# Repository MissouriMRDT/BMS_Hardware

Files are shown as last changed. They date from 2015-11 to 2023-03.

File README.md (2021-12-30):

Battery Management System- this year it DOES THINGS (for real though!).

New for 2022: <br/>
-Designed to monitor an 8s8p LiPo battery pack at a max 33.6V @ 160A peak. <br/>
-The Cell Monitoring circuit uses the AS358MTR-E1 Op-Amp as it could be powered off of pack voltage. <br/>
-Teensy 4.1 used as microcontroller for the board.

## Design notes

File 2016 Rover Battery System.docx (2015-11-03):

2016 Rover Battery System

Mars Rover Design Team

Student Design and Experiential Learning Center

Missouri University of Science and Technology

Josh Jetter

July 10, 2015

Revision History

Table of Contents

List of Figures

List of Tables

Introduction

Battery Pack

Battery Cells

Cell Modules

Battery Management System

Requirements

System Architecture

Monitoring Analog Front-End

Microcontroller

Pack Load Switch

Cooling Fans

Indicators

Serial Data Interface

System Power Supply

Software

Battery Charger

Charging Requirements

Buck-Converter Design

High-Level Converter Design

Inductor Selection

MOSFET Switch Selection

MOSFET Driver Selection

Diode Selection

Filtering Capacitor Selection

Total Losses

Monitoring and Control Hardware

Schematic

Controls Modeling

Software

PCB Layout

Future Work

Acknowledgments

References

Appendices

Appendix A: Inductor Calculations Octave Source Code

List of Figures

List of Tables

Introduction

The battery system for the 2016 rover encompasses everything necessary for the battery pack’s operation, which includes the battery management system, the battery charger, and the battery cells themselves.

Battery Pack

Battery Management System

A core component of the rover’s battery pack is the Battery Management System (BMS) which is responsible ensuring the battery operates efficiently and within a safe operating area (SOA) defined by voltage, current, temperature.

Requirements

The BMS’s functional requirements are split into two categories: protection and management [21]. The protection portion of the BMS is responsible for preventing cell under- and over-voltage conditions, preventing pack over-current conditions, and keeping the battery pack within its temperature limits. These characteristics describe the battery pack’s safe operating area. Table 1 describe the safe operating area characteristics for both individual cells and the entire pack, as well as how the BMS can react to maintain these conditions. The battery pack limits are based on the eight series modules with ten parallel cells as described in the Battery Pack section of this document.

Property | Cell Limit | Pack Limit | BMS Actions
Under-voltage | 2.5V | 20V | Disconnect load; charge pack
Over-voltage | 4.2V | 33.6V | Disconnect charger; balance cells
Over-current | 20A (continuous) | 200A (continuous) | Request reduction of load; disconnect load
Under-temperature | 0°C (charging) -20°C (discharging) | | Heat battery pack (power balancing resistors)
Over-temperature | 50°C (charging) 75°C (discharging) | | Cool battery pack (turn fans on)

Table 1 – Summary of BMS Safe Operating Area Characteristics [20].

When performing the monitoring functions, it is also critical that the BMS considers the importance of transient conditions versus continuous conditions, i.e. it is often acceptable to operate outside of the SOA for brief period of time. For example, the BMS will need to consider the fact that the cells have a higher pulse discharge rating that continuous discharge rating. It would be undesirable for the pack to stop powering the load due to something as harmless as load transient conditions.

In order to achieve the battery protection functional requirements, the BMS must have hardware that is capable of making the SOA characteristic measurements and hardware that can take action to act on this data. The measurement functionality is the responsibility of the BMS’s analog front-end. The ability to disconnect the battery from a load is the responsibility of the BMS’s pack on-off switch. Preventing under- and over-voltage conditions is the responsibility of the pack’s charger hardware, balancing hardware, and the on-off switch. Finally, preventing over-temperature conditions is the responsibility of the pack’s cooling fans controlled by the BMS.

Additional functional requirements for the BMS are considered “battery management” functionalities [21]. This includes state of charge (SoC) estimation, state of health (SoH) estimation, passive cell balancing, emergency stop button support, external reporting of telemetry data, visual SoC indication, and visual telemetry indication.

State of Charge estimation describes the ability of the BMS to determine how much usable charge remains in both cell modules and the entire pack. Since cell open-circuit voltage is not linearly related to cell SoC (see figure 1), it cannot be the sole source of data for pack state of charge measurements. Performing coulomb counting on the battery pack allows for a direct measurement of the remaining charge in the pack, but this falls short in three ways: the BMS does not necessarily know the pack’s full charge capacity, the pack’s charge capacity decrease as it wears out, and the coulomb counting values are prone to drift due to measurement errors (as it is not measured directly, but rather through time-domain integration of the measured pack current). State of Charge estimation will then instead, be based on a fusion of both coulomb counting and open circuit voltage data.

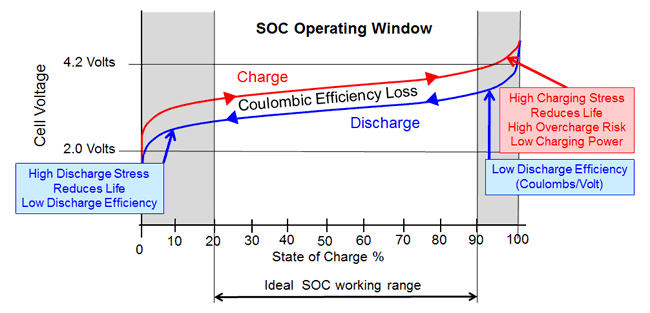
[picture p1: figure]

Figure 1 – Cell State of Charge vs. Cell Open Circuit Voltage [19].

Manufacturing and operating condition variances between individual cells leads to capacity variations in individual cells and thus the SoC of individual cells also varies over time. The inconsistency of SoC amongst individual cells in the battery pack is called cell or battery imbalance [21]. This becomes an issue because the battery pack’s maximum and minimum SoC is limited by the capacity of the smallest cell module if the pack is not balanced. This concept is most clearly demonstrated in figures 2b and 3b, which show a battery pack that are over-charged and over-discharged, respectively, due to cell imbalance. Figure 4 demonstrates how a pack falls out of balance due to self-discharged during storage.

Figure 2 – (a) A Fully Charged, Balanced Four Cell Battery Pack; Versus (b) An Overcharged Battery Pack Due to an Overcharged Cell [21].

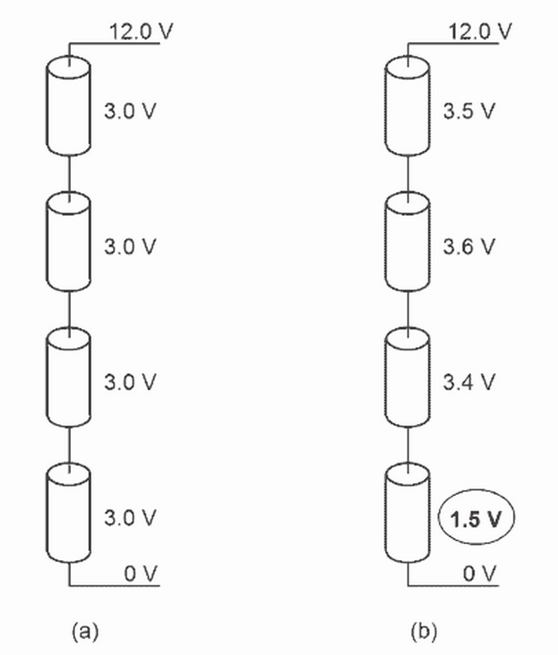
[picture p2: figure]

Figure 3 – (a) A Partially Discharged, Balanced Four Cell Battery Pack; Versus (b) An Over-Discharged Battery Pack Due to an Over-Discharged Cell [21].

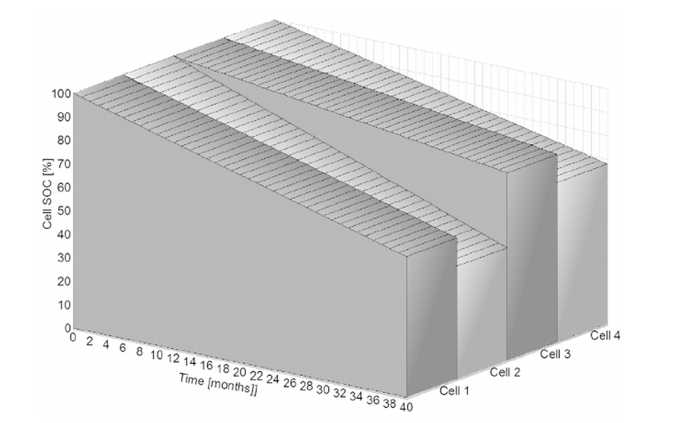
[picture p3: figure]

Figure 4 – Cell State of Charge Vs. Time in Storage [21].

The BMS’s cell balance hardware is responsible for maintaining pack balance. For cost and development time reduction purposes, the BMS will utilize passive cell balancing, and thus can only balance the pack during charging, not discharging.

State of Health estimation is useful for determining the pack’s remaining useful lifetime and its total charge capacity. Estimation of SoH will be the responsibility of the BMS’s master microcontroller in conjunction of the estimates made by the system’s analog front-end measurements.

The BMS will also be responsible for allowing a user to completely power the rover off using an emergency stop button. This will be the responsibility of the master microcontroller and the pack load switch, as well as an externally mounted emergency stop button.

Finally, it is critical that the BMS provide easily consumable telemetry data to the rover’s operator so that they may make informed decisions based on the battery pack’s current state. This will occur in two ways: first through immediately visible indicator hardware built into the battery pack, and second through serial telemetry reported back to the rover’s base station.

In addition to these functional requirements, it is critical that the system’s total component cost is under approximately $200; fits within an area of approximately 40 square inches; has a total weight of less than 1kg; and has a minimal energy drain on the battery pack, especially when the rover is power off.

System Architecture

Adsfads

Monitoring Analog Front-End

The BMS must make a large number of sensitive analog measurements to function properly, including voltage, current, and temperature measurements. Additionally, in order to perform cell balancing, the BMS must drive a large number of balancing switches. Due to the sheer number of analog measurements that are necessary, it is impractical to make all of these connections directly to a microcontroller unit’s ADC. The analog data sources proposed for this system are listed in table 1 below.

Data Source | Number of Independent Measurements | Voltage Measurement Range (V)
Cell Voltage | 8 to 12 (same as number of cells) | 0 to 4.5 (absolute limit) 2.5 to 4.2 (typical)
Pack Current | 1 | -5 to 5 (dependent on sensor)
Pack Voltage | 1 | 0 to 50 (scaled to 0 to 5 or 0 to 3.3)
Charger Output Current | 1 | - 5 to 5 (dependent on sensor)
Charger Input Voltage | 1 | 0 to 50 (scaled to 0 to 5 or 0 to 3.3)
System Output Voltage | 1 | 0 to 50 (scaled to 0 to 5 or 0 to 3.3)
Temperature | 2 | 0 to 3.3 or 0 to 5

Table 1 – Analog Data Sources Measured by the BMS.

Since as many as 19 different analog data sources may be measured by the BMS at any given time, it is necessary to multiplex the channels of the master microcontroller’s ADC. High quality analog multiplexers are often expensive, however, and require this approach requires the microcontroller to dedicate processor cycles to MUXing and analog-to-digital voltage conversion. Additionally, it poses a safety hazard by potentially exposing the low-voltage electronics of the microcontroller to full pack voltage (potentially over 50V). An alternative solution to a multiplexer is the use of a dedicated analog front-end ASIC that would make measurements, perform analog-to-digital conversion, and provide an isolated digital interface to the microcontroller.

Linear Technology’s LTC6802 Battery Stack Monitor IC has been selected for this application [13]. As an analog front-end IC, it can measure 2 to 12 cell voltages, perform passive balancing on 2 to 12 cells, and measure temperature from two external temperature sensors. It is daisy-chainable if additional measurements are necessary and provides a serial data interface to the master microcontroller. Figure 1 shows a high-level overview of the IC’s typical application. Figure 2 shows the IC’s pinout.

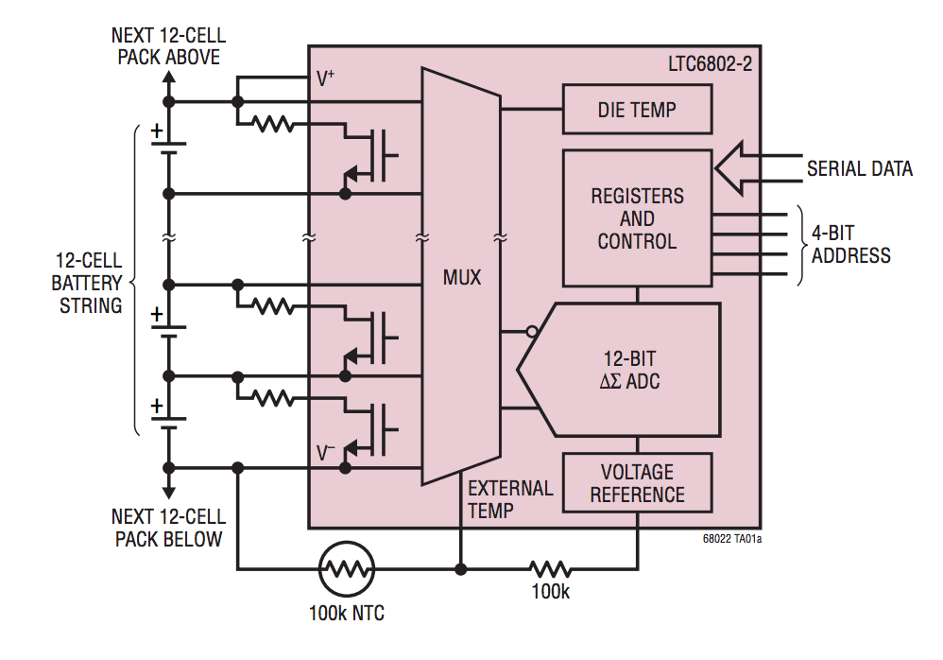
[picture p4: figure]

Figure 1 – Typical Application of the LTC6802-2.

Figure 2 – Pinout of the LTC6802-2.

For the purposes of this application each connection between a cell module and the IC consists of a one-pole RC filter, transient voltage suppression circuit, and an off-IC balancing circuit. An example of one such circuit is shown in figure 3 below. This circuit is repeated for each of the eight cell modules in the pack.

The RC filter is used to suppress noise in the cell voltage measurements that is common when the pack is exposed to load transients. Values of 100 Ohms for the resistor and 100nF for the capacitor were selected to produce a low-pass filter with a cutoff frequency of approximately 16kHz. A large capacitor was not used in order to allow the LTC6802 IC to more easily detect cell measurement line disconnections [13].

A simple zener diode between cell filter nodes serves as transient voltage snubber circuit.

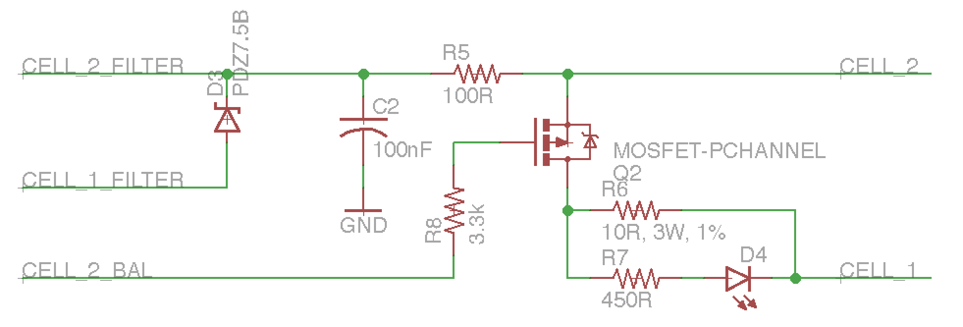
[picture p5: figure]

Figure 3 – Cell Module Interface Circuit.

Finally an external MOSFET and power resistor were included for passive cell balancing. Although the IC is capable of performing balancing without external hardware, its maximum balancing current is limited to 50 to 100mA (depending on the exact balancing conditions). This is due to the IC’s thermal dissipation characteristics, as shown in figure 4. The IC’s typical internal cell discharge current may be determined from the graph in figure 5.

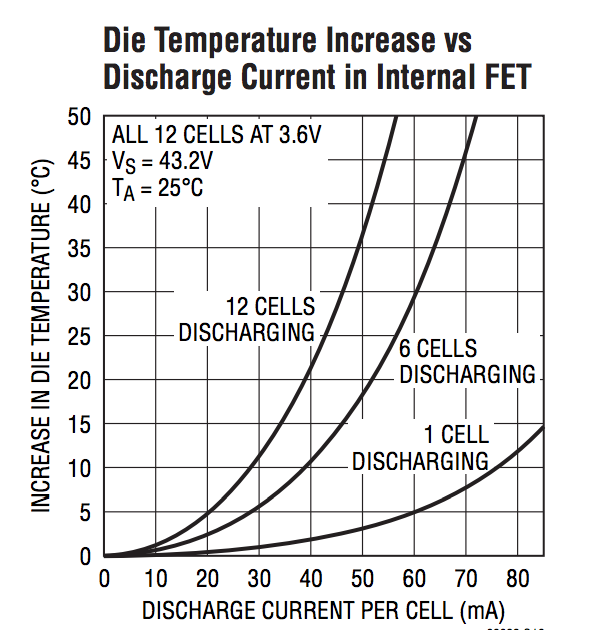
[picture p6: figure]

Figure 4 – LTC6802 Temperature Characteristics vs. Cell Discharge Current.

Figure 5 – The LTC6802’s Internal Discharge Resistance vs. Battery Cell Voltage.

The external balancing circuit consists of a small SOT23 package P-Channel MOSFET driven by the LTC6802 IC and a 10-Ohm, 3W, through-hole power resistor. For a cell voltage of 4V, this allows for a balancing current 400mA without overheating issues. Additionally, a small LED is connected in parallel to the power resistor to provide a visual indication that the balancing circuit is active.

For the purposes of battery pack thermal monitoring (and with cooling fans, management) two external NTC thermsistors may be connected to the LTC6802 IC as shown in figure 6. The NTC is connected in a voltage divider configuration to the IC’s analog voltage reference and measured by its on-board ADC. A voltage buffer circuit is included between the IC’s analog reference and the temperature sensor in order to better support a range of NTC resistor values. The “Temp_1” and “Temp_2” nets are connected to the IC’s temperature VTEMP1 and VTEMP2 pins, respectively.

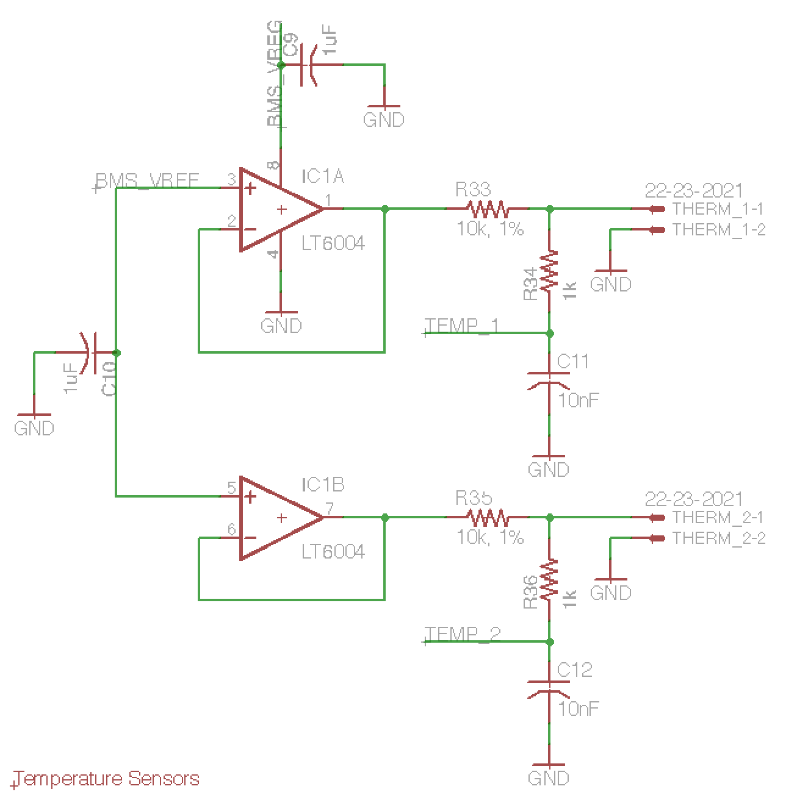
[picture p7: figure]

Figure 6 – Supporting Circuitry for External NTC Thermsistors.

In addition to cell voltage measurements, total pack voltage may be measured by the master microcontroller directly through a resistor divider network. The divider network scales the pack’s maximum voltage of 33.6V to under the 5V maximum of the master microcontroller’s ADC.

A hall-effect sensor is responsible for making pack voltage measurements and reporting them to the master microcontroller. The ACS770 has been selected for this application as it can support the full pack current of 200A in both directions (charging and discharging), is easily powered from a 5V DC supply, and outputs and analog voltage between 0V and 5V corresponding to total pack current [22]. Figure 7 depicts the circuitry support pack voltage and current measurements.

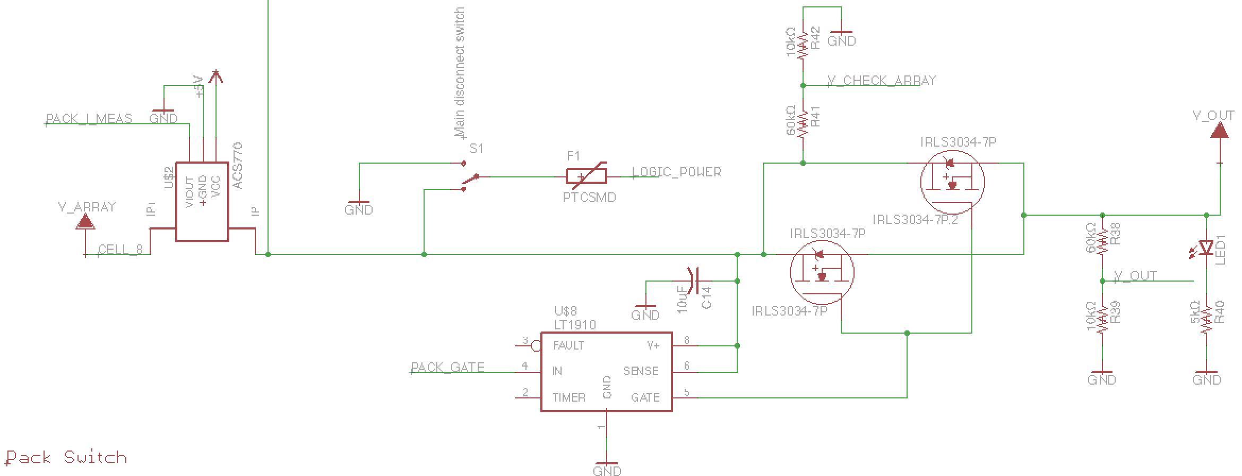
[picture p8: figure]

Figure 7 – Pack Current and Voltage Measurements; Load Switch MOSFET.

The analog front-end IC is only capable of supporting analog signal I/O for the BMS, it does not have any inherent battery management or protection logic built-in. This is the responsibility of the BMS’s master microcontroller. Thus it is necessary to provide a digital interface between IC and the microcontroller. For the LTC6802 this interface is very similar to SPI, and is depicted in figure 8 below.

Figure 8 – LTC6802 to Microcontroller Serial Data Interface.

Microcontroller

Although the analog front-end IC is useful for aggregating battery pack data, it cannot make decision about the pack on its on. A microcontroller unit is necessary for monitoring pack operating state, activating balancing circuitry, controlling charging, and connecting and disconnecting the pack from its load. The I/O requirements for the microcontroller are summarized in table 2.

Function | Type of I/O Port | Quantity of Ports/Pins
Analog Front-End Communication | SPI | 1
Cooling Fan Control | PWM | 4
Cooling Fan Speed Feedback | GPIO | 4
Buzzer Alarms | PWM | 2
LED Gauge | GPIO | 4
Emergency Stop Input | Digital Input – Interrupt | 2
Pack Current Measurement | ADC | 1
Pack Voltage Measurement | ADC | 1
Pack Switch | GPIO | 1
Pack Output Voltage Measurement | ADC | 1
Charger Control | PWM | 1
Charger Current | ADC | 1
Charger Input Voltage Measurement | ADC | 1
Serial Debug Port | USB | 1
External Communication | Ethernet | 1
External Power Supply Communication | GPIO | 2
External LCD Screen | GPIO | 11

Table 2 – Microcontroller I/O Requirements.

In addition to meeting these I/O requirements, the microcontroller needs to operate at sufficiently high speed to frequently monitor the pack’s state, enable/disable balancing, update the charger power converter control loop, and maintain external communications. A microcontroller with a clock speed of at least 16MHz should be capable of this. Additionally, the microcontroller should be low power and capable of entering a low power sleep mode, as it will always be operating once installed in the pack. For ease of prototyping, it is also ideal if a development board is available for the microcontroller.

The MSP432P401R by Texas Instruments meets these requirements. It is part of TI’s MSP432 family of microcontrollers, a hybrid of the ubiquitous ARM architecture and TI’s low power MSP430 architecture. The microcontroller operates at up to 48MHz, meets the I/O requirements (with the exception of not having an on-board Ethernet PHY module), and consumes 90μA/MHz in low power mode [14]. Texas Instruments also produces a low cost development board targeting the microcontroller. The connections between the microcontroller’s I/O ports and the BMS hardware are described in table 3. Only pins made accessible by the Launchpad development board are listed [15].

Pin | Functionality | Relevant Hardware Peripherals | Connection
1.5 | Digital Input (Interrupt) | | E-Stop 1 Input
1.6 | Digital Input (Interrupt) | | E-Stop 2 Input
1.7 | GPIO | | External Power Supply Communication
2.3 | GPIO | | External Power Supply Communication
2.4 | PWM | TA0, CCR1 | Fan 1 Speed Control
2.5 | PWM | TA0, CCR2 | Fan 2 Speed Control
2.6 | PWM | TA0, CCR3 | Fan 3 Speed Control
2.7 | PWM | TA0, CCR4 | Fan 4 Speed Control
3.0 | GPIO | | Fan 4 Tachometer
3.2 | GPIO | | Fan 3 Tachometer
3.3 | GPIO | | Fan 2 Tachometer
3.5 | GPIO | | LCD Screen RS
3.6 | GPIO | | LCD Screen R/~W
3.7 | GPIO | | LCD Screen EN
4.0 | GPIO | | LCD DB[0]
4.1 | GPIO | | LCD DB[1]
4.2 | GPIO | | LCD DB[2]
4.3 | GPIO | | LCD DB[3]
4.4 | GPIO | | LCD DB[4]
4.5 | GPIO | | LCD DB[5]
4.6 | GPIO | | LCD DB[6]
4.7 | GPIO | | LCD DB[7]
5.0 | GPIO | | Fan 1 Tachometer
5.1 | ADC | ADC4 | Charger Voltage
5.2 | ADC | ADC3 | Charger Current
5.3 | ADC | ADC2 | System Output Voltage
5.4 | ADC | ADC1 | Pack Voltage
5.5 | ADC | ADC0 | Pack Current
5.6 | PWM | TA2, CCR1 | Buzzer 1
5.7 | PWM | TA2, CCR2 | Buzzer 2
6.0 | GPIO | | Pack Load Switch
6.1 | Digital Input (Interrupt) | | Wiznet Data Available Interrupt
6.2 | SPI SS | eUSCI_B1 | LTC6802 CSBI
6.3 | SPI SCLK | eUSCI_B1 | LTC6802 SCKI
6.4 | SPI MOSI | eUSCI_B1 | LTC6802 SDI
6.5 | SPI MISO | eUSCI_B1 | LTC6802 SDO
6.6 | Digital Input (Interrupt) | | LCD/LED Indicator On/Off Button
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
8.0 | PWM | TA1, CCR0 | Charger Power Converter Control
8.2
8.3
8.4
8.5
8.6
8.7
9.0 | GPIO | | Wiznet Reset
9.1
9.2
9.3
9.4 | SPI SS | eUSCI_A3 | Wiznet SS
9.5 | SPI SCLK | eUSCI_A3 | Wiznet SCLK
9.6 | SPI MISO | eUSCI_A3 | Wiznet MISO
9.7 | SPI MOSI | eUSCI_A3 | Wiznet MOSI
10.0 | GPIO | | LED Shift Register CLR
10.1 | GPIO | | LED Shift Register RCK
10.2 | GPIO | | LED Shift Register SER_IN
10.3 | GPIO | | LED Shift Register SRCK
10.4
10.5

Table 3 – Microcontroller I/O Connections. Unused Pins are Shaded.

Pack Load Switch

The master microcontroller is responsible for connecting/disconnecting the battery pack from its load by commanding the output of a MOSFET driver IC. The microcontroller will switch the pack off when the battery pack is operating outside of its safe operating area or if the emergency stop button is activated. The hardware responsible for this functionality is shown in figure 7.

In order to handle the 200A continuous discharge the pack is capable of sustaining, as well as larger transient load currents, the load switch consists of two International Rectifier IRLS3034 Power MOSFETs connected with drain and source junctions in parallel [16]. The MOSFETs case temperature characteristics versus drain current are shown in figure 8. Each MOSFET should be capable of handling 200A independently, thus together they should be able to sustain load transients on the order of 400A without significant overheating issues. The MOSFETs are connected in parallel without load balancing resistors because in general they will be operated in the saturation region with low Rdss(on), and thus their negative temperature coefficient properties should ensure proper load current balancing between the two devices [17].

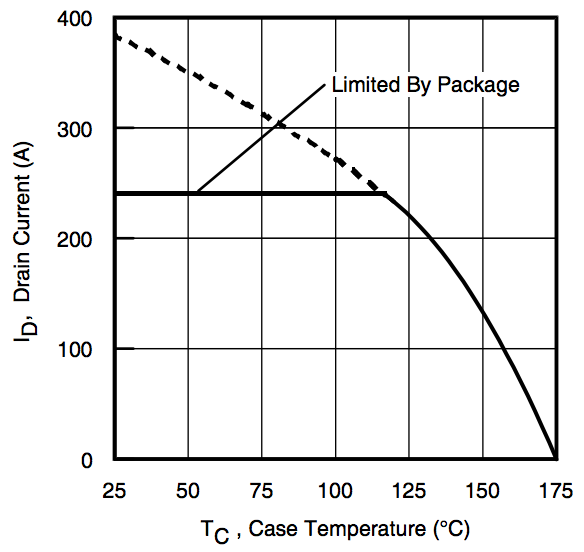
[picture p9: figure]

Figure 8 – IRLS3034 Case Temperature vs. Drain Current.

The two MOSFETs will be driven by a single LT1910 high side MOSFET driver IC [18]. As the FETs will generally operate in the saturation for long periods of time, turn-on time, and therefore gate driver current and gate charge are not serious design concerns. The ability of this MOSFET and driver configuration to sustain 200A of load current continuously has been empirically verified by the team in past years.

Cooling Fans

In order to ensure the battery pack is properly cooled when under heavy load conditions, connections for four external cooling fans have been made available. The four fans can have their speed individual controlled by driving an onboard MOSFET with PWM. Additionally, the master microcontroller can measure tachometer feedback from each fan. The fans are connected to the board via a standard 0.1” pitch three-pin connector. Support hardware for this configuration is shown in figure 9.

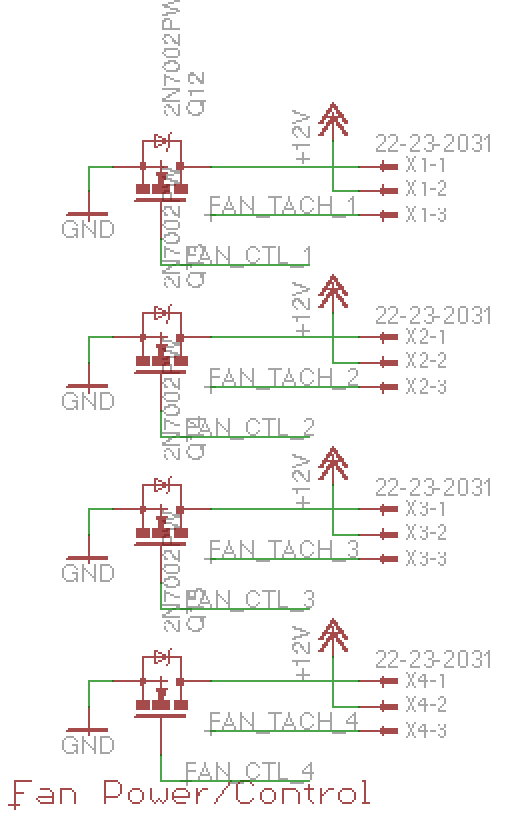
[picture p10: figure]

Figure 9 – Cooling Fan Connectors.

Indicators

Two types of user interface indicators are incorporated into the design to provide the user with information about the state of the battery pack: a 10 segment LED bar graph and a 16x2 character LCD display.

The LED bar graph will serve as a state of charge indicator with each segment corresponding to 10% of the total state of charge. The LED bar graph will be controlled by a serial data stream from the master microcontroller to a high power, open-drain shift register which will drive the LEDs. This circuit is depicted in figure 10 and an example of the bar graph component is shown in figure 11. The shift register component is the TI TLC6C5912-Q1 and the bar graph is the Kingbright DC7G3HWA [23][24]. The shift register output enable pin is connected to an external momentary SPST switch so that the indicator is only lit when the user holds down on the button, preventing unnecessary drain on the battery pack.

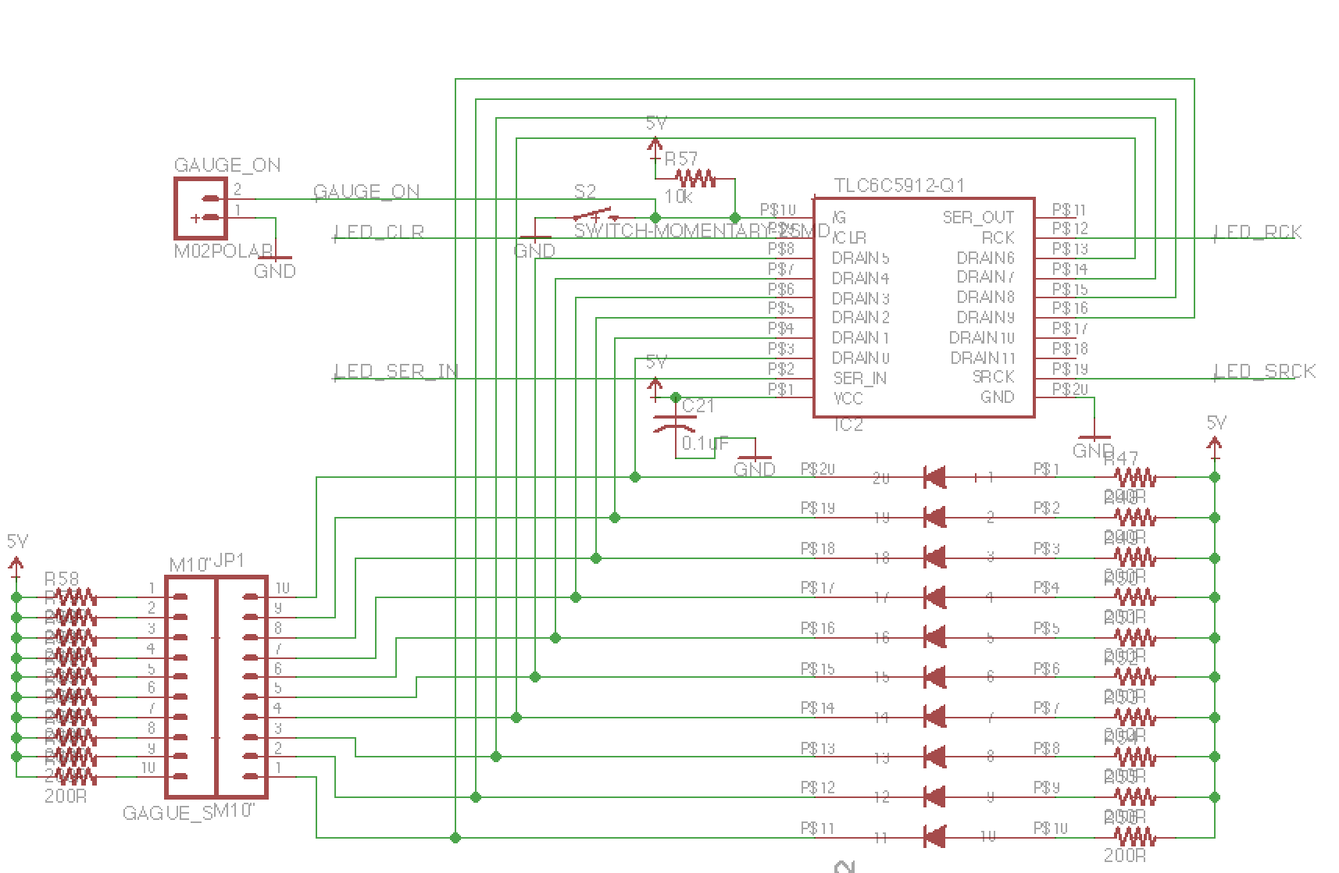
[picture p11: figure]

Figure 10 – LED Bar Graph Indicator, Shift Register Driver, External Mounting Connectors, and Indicator Momentary Power Switch.

Figure 11 – Sample LED Bar Graph Component, Unpowered.

The second indicator will be a 16x2 character LCD display. This will provide simple telemetry data about the battery pack’s status to the user.

Serial Data Interface

The master microcontroller makes two telemetry/telecommand serial data interfaces available: a USB serial logging interface for reading data from a PC and an RS-485 serial interface for communicating with the battery pack’s power board (which is the BMS’s primary load). The serial interface circuitry between the BMS and power board is shown in figure 12 below.

Figure 12 – RS-485 Serial Data Interface to BMS Master Microcontroller.

System Power Supply

Alsdjfladskjfkalds

Software

Afdjlaskfjaldskjfkls

Battery Charger

An integrated charger for the battery pack is desired in order to charge the batteries at their rated-charging speed and to simplify the charging process for the end-user. The preliminary charger will accept a DC-input greater than pack voltage for a buck-converter based charger. A future revision of the charger could be a buck-boost converter that would also accept charging voltages below pack voltage.

Charging Requirements

The selected cells are rated for two charging algorithms: a standard charge and a fast charge. As their names indicate, the standard charging algorithm is slower, but results in increased cell lifetime; while the fast charge is significantly faster but will reduce cell lifetime.

The standard charging algorithm consists of two phases: the constant current (CC) phase and the constant voltage phase (CV). For a standard charge, CC charging first takes place at 1250mA (per parallel cell), then CV charging takes at 4.2V (per series cell) until charging current tapers to 50mA per cell. For a fast charge, CC charging first takes place at 4000mA (per parallel cell), then CV charging takes at 4.2V (per series cell) until charging current tapers to 100mA per cell. After fast charging the batteries must rest for 10 minutes.

Since the fast charging algorithm places the greatest demand on the battery charger, it will be used for determining battery charger requirements. For the proposed 10 parallel/8 series (10p8s) battery pack, the minimum pack voltage will be 20V and the maximum pack voltage will be 33.6V. Thus the charger must be capable of constant voltage charging at 33.6V. Since there are ten cells in parallel, the charger must be capable of sourcing 40A during CC charging. The worst-case power draw on the charger occurs during a 33.6V, 40A charging period (an unlikely load point for the battery pack), which is equal to 1344W. Design goals for the charger are summarized in table 1 below.

Parameter | Minimum | Nominal | Maximum | Units
Output Voltage | 20.0 | | 33.6 | V
Output Current | 12.5 | | 40.0 | A
Input Voltage | 35 | | 50 | V
Rated Power | | 1350 | | W
Weight | | 200 | 1000 | g
Board Area | | | 24 | Sq. in.

Table 1 – Charger Design Parameters

Buck-Converter Design

The buck-converter topology was selected for the first revision of the battery charger due to its simplicity. A high-level converter design is presented in this section that assumes nearly ideal components. This serves as the base design for the more detailed, non-ideal analysis in the subsequent sections.

A conceptual equivalent circuit for a buck converter is shown in figure 1. It consists of an input voltage source, a high frequency switch, a rectifying diode, a switching inductor and filter capacitor (which together form a second order low pass filter), and a load resistor. The goal of the design process covered in this section is to select an appropriate inductor value, switching frequency, and filter capacitor value which function over the full operating range of the converter. Since this converter is being used for battery charging, it will need to operate over a few particular operating points that represent the constant-current and constant-voltage charge curves shown in figure 2. The worst-case values for these operating points are summarized in table 2. Note that for these initial calculations it is assumed that the on-state resistance of the converter’s switch is negligible and that the series resistance of the inductor is zero. Additionally the battery pack will be approximated as an equivalent load resistance. More accurate models are presented later.

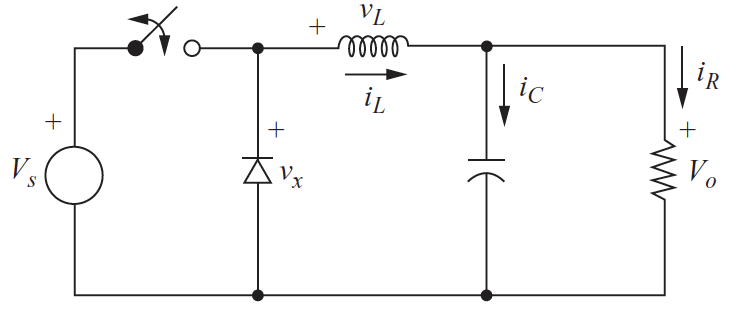
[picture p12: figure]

Figure 1 – Simplified Equivalent Circuit of a Buck Converter [25].

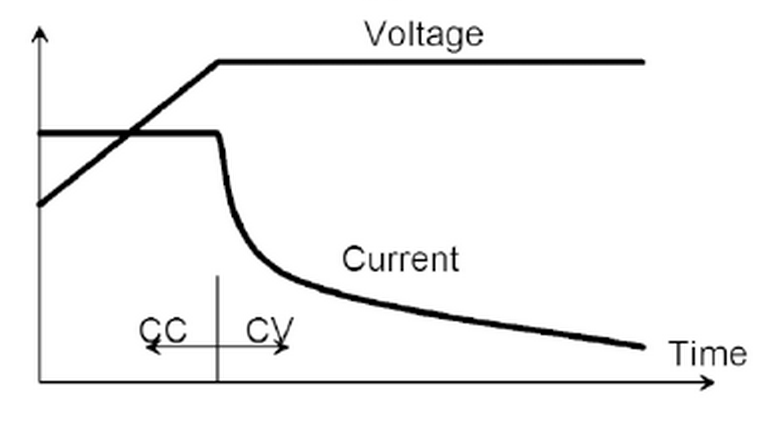
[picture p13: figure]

Figure 2 – Current and Voltage Operating Points for CC and CV Charging [21].

Load Case | Control Mode | Input Voltage | Output Voltage | Output Current
CC Charging | Current Mode | 36V | 20V to 33.6V | 40A
| Current Mode | 48V | 20V to 33.6V | 40A
CV Charging | Voltage Mode | 36V | 33.6V | >= 500mA
| Voltage Mode | 48V | 33.6V | >= 500mA

Table 2 – Buck-Converter Operating Points.

First and inductor value and switching frequency must be chosen. Since there is a trade-off between inductor size and switching frequencies, inductor values were calculated over a series of potential frequencies. The final inductor and switching frequency is a compromise between cost and performance and is explored in detail in the section titled Inductor Selection. The following design calculations are based on an operating point analysis for continuous inductor current presented in Hart’s Power Electronics [25]. First of all for the various load cases, the duty cycle must be considered. The switching duty cycle for the ideal buck converter is:

D=(V_o)/(V_s)

Where:

D = Duty Cycle (0 to 1 for 0% to 100% of switching period T)

Vo = Output Voltage

Vs = Input (Source) Voltage

Furthermore, the minimum inductor value for a given load, switching frequency, and duty cycle is:

L_(min) = ((1-D)R)/(2f)

Since our load’s equivalent resistance varies depending on the charger’s operating point, and a steady-state voltage and/or current instead define this operating point, the equation for minimum inductor value may be redefined in terms of load voltage and load current, Io:

L_(min) =((1-D)(V_o)/(I_o))/(2f)

The duty-cycle, output voltage, and output current are all related to one another. For voltage mode control (during CV charging), Vo will be held constant, leading to a variation in Io over the defined operating limits of the battery pack. For current mode control (during CC charging), the converter will attempt to hold Io constant by varying Vo over the operating limits of the battery pack. And regardless, the duty-cycle is a function of converter input and output voltages, as shown in equation 1. Since duty cycle is a direct function of the input and output voltage operating conditions, it is further useful to rewrite equation 3 using equations 1 to produce equation 4:

L_(min) =((1-(V_o)/(V_s))(V_o)/(I_o))/(2f)

L_(min) =((V_o)/(I_o)-(V_o^2)/(V_s I_o))/(2f)

In order to determine the necessary inductor size for various switching frequencies, it is easiest to break the converter into two operating cases: voltage mode control and current mode control. This means that one of the variables is held constant in equation 4, and thus makes the value of the inductor in equation a function of two variables. For constant current it is a function of output voltage and input voltage; for constant voltage it is a function of output current and input voltage. To make it possible to iterate over a series of frequencies, it is useful to breakdown the two above case into two more cases each, one for an input voltage of 36V and one for an input voltage of 48V. These voltages are selected for analysis, as they are common voltage levels for DC power supplies that will be used for the charger. Thus, the four possible load cases are summarized in table 3.

Load Case | Control Mode | Input Voltage (Vs) | Output Voltage (Vo) | Output Current (Io) | Switching Frequency (f)
1a | Current | 36V | Variable | 40A | Variable
1b | Current | 48V | Variable | 40A | Variable
2a | Voltage | 36V | 33.6V | Variable | Variable
2b | Voltage | 48V | 33.6V | Variable | Variable

Table 3 – Four Charger Load Cases for Analysis.

Inductor values for each the four cases listed in table 2 were calculated iteratively using the computer program GNU Octave [26]. These results are summarized in figures 4 through 7.

Figure 4 – Inductance Values for Load Case 1a.

Inductor Selection

The selected inductor is largely dependent on the selected switching frequency for the converter. Higher switching frequencies lead to higher switching losses and create more stringent requirements for the converter’s MOSFET switches and MOSFET drivers, however allow for the use of smaller magnetics. Lower switching frequencies require an inductor of higher rated inductance and thus a larger, heavier inductor. Inductors for various switching frequencies are presented in this section.

Based on the analysis in the previous section, a switching frequency of in the range of 50kHz to 500kHz is likely. The requirements for inductors for frequencies in this range are presented in table 2 below.

Parameter | 50kHz Inductor | 125kHz Inductor | 250kHz Inductor | 500kHz Inductor
Inductance (μH) | 132 | 88 | 44 | 22
RMS Current (A) | 40 | 40 | 40 | 40
Saturation Current (A) | 40 | 40 | 40 | 40
Ripple Current (A)

Table 2 – Inductor Requirements for Various Switching Frequencies.

Various suppliers were searched for inductors that meet the above requirements. The selected inductor for each switching frequencies was selected by best meeting the required electrical characteristics while minimizing cost, weight, and size. Possible inductors are presented in table 3 below. Values for the table were derived from the manufacturer datasheet tables and the curves shown in figures 1, 2, and 3.

Parameter | 50kHz Inductor | 125kHz Inductor | 250kHz Inductor | 500kHz Inductor
Part Number | WCM 306-8 | WCM 306-10 | WCM 306-13 | AGP4233-223ME
Supplier | West Coast Magnetics | West Coast Magnetics | West Coast Magnetics | Coilcraft
Price ($)
Inductance (μH) | 131 | 91 | 49 | 22
Inductance Tolerance | | | | +/- 10%
Weight (g) | 1000 | 1000 | 1000 | 135
DCR (mOhms) | 2.80 | 1.89 | 1.03 | 2.95
Size - Length, Width, Height (cm) | 7.75 x 7.24 x 7.62 | 7.75 x 7.24 x 7.62 | 7.75 x 7.24 x 7.62 | 4.22 x 3.58 x 2.80
RMS Current (A) | 33.0 | 39.0 | 55.0 | 34.0
Saturation Current, 10% (A) | 37 | 45 | 60 | 32.8
Saturation Current, 20% (A) | 39 | 47 | 65 | 35.4
Saturation Current, 30% (A) | 42 | 50 | 67 | 36.6
Ripple Current (A)
Temperature (C) | | | | 125

Table 3 – Selected Inductor Characteristics for Various Switching Frequencies[1][2].

The two best inductors for this application are the WCM-306-10 (a 91uH inductor produced by West Coast Magnetics) and the AGP4233-233ME (a 22 uH inductor produced by Coilcraft).

The WC Magnetics inductor is well suited for this application because it allows for a reasonable switching frequency (125kHz) while still meeting the current requirements of the converter (the 39.0Arms is the limiting current rating; the core will not saturate within the converter’s operating limits). Unfortunately this inductor is quite large, weighing 1kg and having a board surface area of 56.11cm² (8.70in²). This makes the inductor ideal for an off-rover charger; however, it may prove to be too large for an integrated charger.

The Coilcraft inductor is also well-suited for this application largely due to small-size. It weighs only 135 grams and uses only 15.10cm² (2.34 in²) of board space. This is 86% savings in weight and 73% savings in volume compared to the WC Magnetics inductor. Unfortunately this inductor is not capable of supporting the full rated current of the charger, limited by a 34.0Arms current and a 32.8A saturation current for a 10% loss of inductance. (More detailed analysis is required to demonstrate this inductors performance over various charger operating points due to the lower saturation current.)

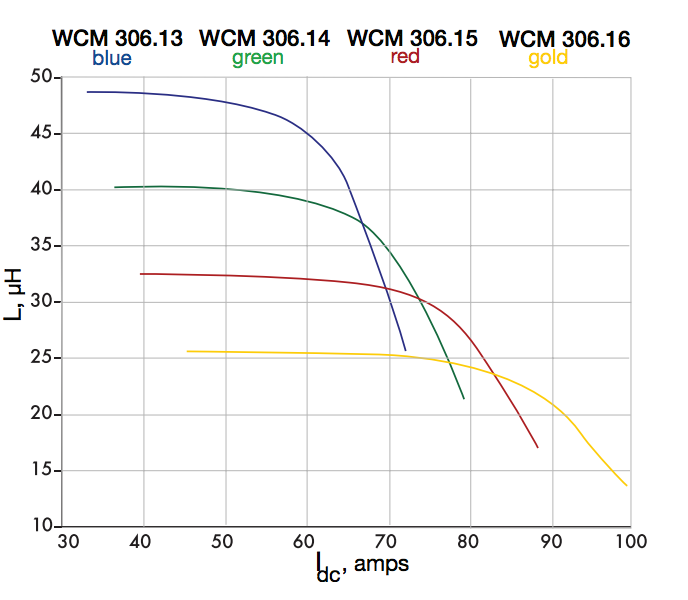
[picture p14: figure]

Figure 1 – Saturation Current for Inductor WCM 306.13.

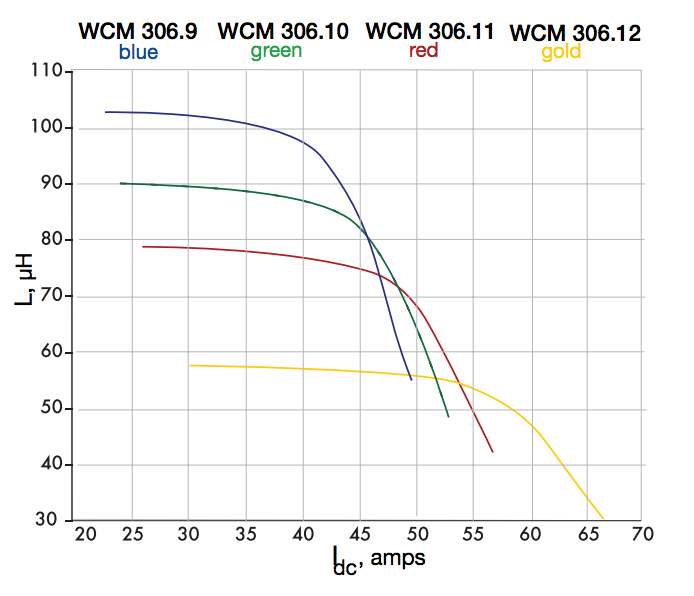
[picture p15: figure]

Figure 2 – Saturation Current for Inductor WCM 306.10.

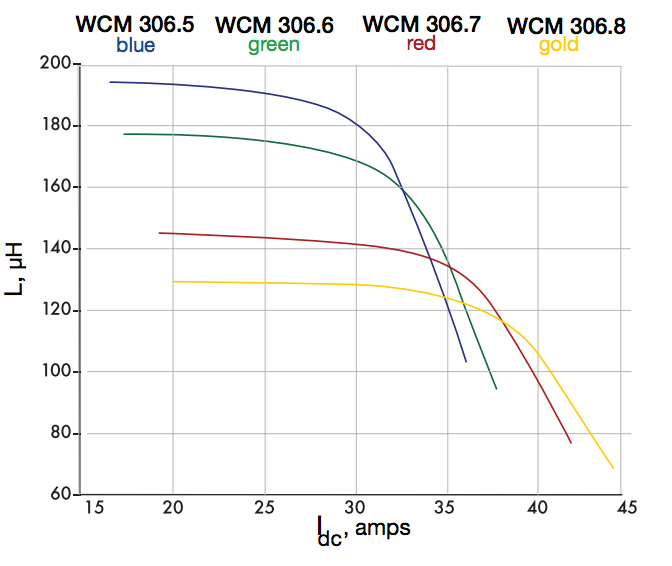
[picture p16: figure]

Figure 3 – Saturation Current for Inductor WCM 306.8.

Figure 4 – Saturation Current for the Coilcraft Inductors.

There are two major sources of inductor losses: AC-current induced core losses and DC equivalent-resistance heat losses. For each of the selected inductors the core losses are negligible compared to the resistive heating loses, so they are ignored here. The resistive losses may be calculated for both inductors using the maximum RMS current of the charger and the equivalent DC resistance of the inductor:

P_(heat) =I_(RMS)^2 R_(DC)

For the Coilcraft inductor:

P_(heat) =40^2 ×0.00295=4.72W

For the selected WC Magnetics inductor:

P_(heat) =40^2 ×0.00189=3.02W

For the Coilcraft inductor, the manufacturer’s website indicates this would lead to approximately a 45°C increase in inductor temperature. Furthermore, the temperature derating curve (see figure 4) indicates that this temperature rise would not be an issue for a wide range of ambient temperatures. WC Magnetics does not publish data on their inductors’ thermal resistance, so there is not a direct method to calculate this part’s temperature rise above ambient; however, it is possible to assume it would remain within normal operating conditions as 40A is far below the part’s rated RMS current.

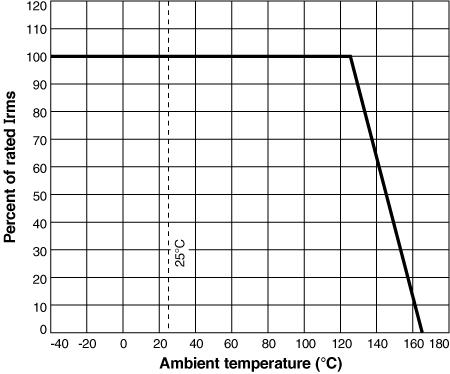
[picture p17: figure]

Figure 4 – RMS Current Temperature Derating Curve for AGP4233-223ME [3].

MOSFET Switch Selection

As discussed in the section on inductor selection, there is a trade-off between switching frequency, inductor requirements, and MOSFET requirements.

For this type of switching converter, the MOSFET is a large source of losses. Losses occur largely in two regions of the switch’s operation: the linear region when the switch is between its “on” and “off” states, and in the saturation region when the switch is “fully on.” Losses in saturation mode are most easily modeled by an equivalent on-state resistance known as the “rds(on).” Losses in the linear mode are more complex to model and much greater than those when the MOSFET is in the saturation region. Therefore it is important to minimize the time that the MOSFET operates in the linear region. This time is dictated by a variety of factors, including gate capacitance, body diode capacitance, and ajlkdfjakd [4]. Additionally the functionality of the MOSFET will depend on its thermal characteristics. Potential MOSFETs for this application are presented in table 4 below.

Part Number | CSD18532KCS | IRFH7191 | IRFH7188 | IRFH7185
Manufacturer | Texas Instruments | International Rectifier | International Rectifier | International Rectifier
Package | TO-220 | PQFN 5x6 | PQFN 5x6 | PQFN 5x6
Price ($/1 unit) | $2.79 | $2.87 | $2.43 | $3.64
VBRDSS (V) | 60 | 100 | 100 | 100
VGS,Max (V) | 20 | 20 | 20 | 20
RDS(on) (mOhms) | 4.2 | 8 | 6 | 5.2
Qg (nC) | 44 | 26 | 33 | 36
Qgd (nC) | 6.9 | 8.3 | 11 | 11
Id @ T=25C (A) | 100 | 80 | 105 | 123
Ciss (pF) | 3900 | 1685
Coss (pF) | 470 | 836
Qrr - Diode (nC) | 127 | 126
RΘJC (°C/W) | 0.6 | 1.2
RΘJA (°C/W) | 62 | 35
Q*R | 185 | 208 | 198 | 187

Table 4 – Comparison of potential switching MOSFETS with a Q*R figure of merit; unit price collected from Digikey [5][6][7][8].

With modern FET technology, the selection of a MOSFET capable of sustaining 40A continuous in the on-state is trivial. A buck-converter by nature, however, will rarely operate with the switching FET continuously in the on-state. During transitions between the on- and off-states the FET will operate in a linear/triode region in which significantly greater switching losses will occur. Therefore, in order to minimize the total switching losses, it is essential that the MOSFET remain in the linear region of operation for the shortest period of time possible. This transition time is dictated by how quickly the gate-to-source voltage can be transitioned by the driver circuit. In ideal conditions, this is nearly instantaneous. A real-world trade off in the construction of high-current FETs, however, is the presence of a significant capacitance at the gate of the MOSFET, which contains a large charge that must be transferred by the driver circuit. For MOSFETs with a large gate charge this can require pulses of many amperes to switch the MOSFET quickly. If this switching transition is not sufficiently minimized, the converter will incur significant switching losses and the MOSFET will overheat. Typically, there is a tradeoff between minimizing the Rds,ON and the gate charge of a MOSFET. Additionally, some manufacturers produce MOSFETs with low gate charges specifically for high-speed switching applications.

Of the MOSFETs listed in table 4, the IRFH7191 is best suited for this application. All of the MOSFETs have a similar Q*R figure of merit, which indicates the switches performance for both minimizing loss during operation in the saturation region and it ability to be switched between the on and off states quickly so as to minimize time in the linear region of operation [12]. As the RDS(on) values of all the MOSFETs were appropriate for this application, the 7191 was selected for its especially low gate charge and input capacitance; allowing it to perform well during high speed switching.

Power losses in this switch may be estimated by analyzing its performance independently in two operating regions: the linear/triode region during switching; and the saturation region during its on-state [4]. In the on-state the MOSFETs losses may simply be modeled as a series resistance, equal to the value of RDS(on) provided in the datasheet. It is important to note that the value of RDS(on) also varies over temperature, so it is important to account for this in analysis. This characteristic is shown in figure 5 below.

Assuming that the driver circuit ensures MOSFET operation in full saturation (by ensuring VGS is greater than approximately 8V), then at 25°C it is reasonable to assume an RDS(on) of approximately 6.5mΩ, and at 125°C it is reasonable to assume an RDS(on) of 11mΩ. Note that there is a significant increase in switching losses as the FET’s temperature increases. Standard full-load conditions for this charger are specified to be 40A (although lower limits may exist for some inductors due to core saturation). Using these values, the power loss in the FET may be calculated for both temperature conditions:

P_(loss) =I_(DS)^2 R_(DS(on))

For 25°C:

P_(loss) =40×6.5=260mW

And for 125°C:

P_(loss) =40×11=440mW

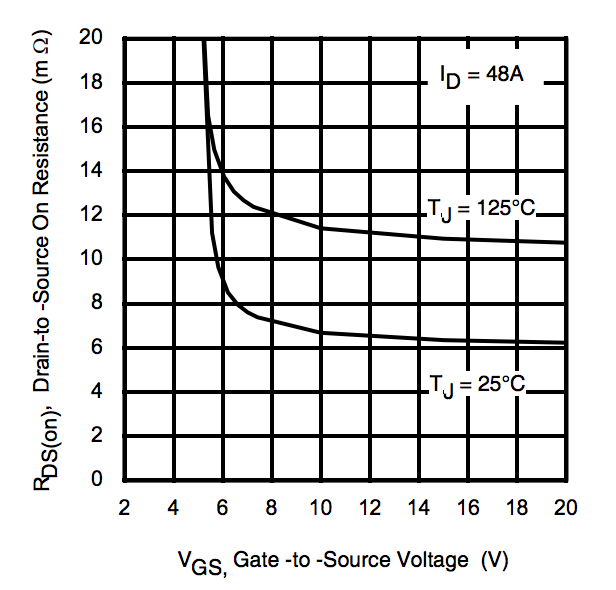
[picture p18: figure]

Figure 5 – IRFH7191 RDS(on) vs. VGS at 25°C and 125°C.

Analysis of switching losses in the linear region is more complicated, as there are many sources of switching losses [4]. The following sources of switching losses may be calculated with the parameters of the MOSFET which are made available from the manufacturer: turn-off losses, turn-on losses, body diode recovery losses, gate charge losses, and output capacitance losses. These losses are also closely related to the characteristics of the driver circuit; a more powerful driver circuit will reduce the time the MOSFET operates in the linear region.

For the purposes of these analyses, a 2.4A peak driver pull-up current will be assumed, based on typical performances of the LTC4440 high-side high-speed driver IC (see figure 6) [10]. Furthermore, the MOSFET transitions through the linear region as the gate driver removes charge from the MOSFET’s gate. The charge at the gate is related to the MOSFET’s gate to source voltage by the curve shown in figure 7. Note that this is not a purely linear relationship, therefore for turn-on and turn-off losses in the MOSFET, it is useful to analize the MOSFET’s transition in three stages (corresponding to the three linear pieces of the curve in figure 7). Furthermore, the on-state resistance of the MOSFET’s channel is related to the gate-to-source voltage by the curve in figure 8.

Figure 6 – Peak Driver Pull-Up Current for the LTC-4440 High-Side MOSFET Driver.

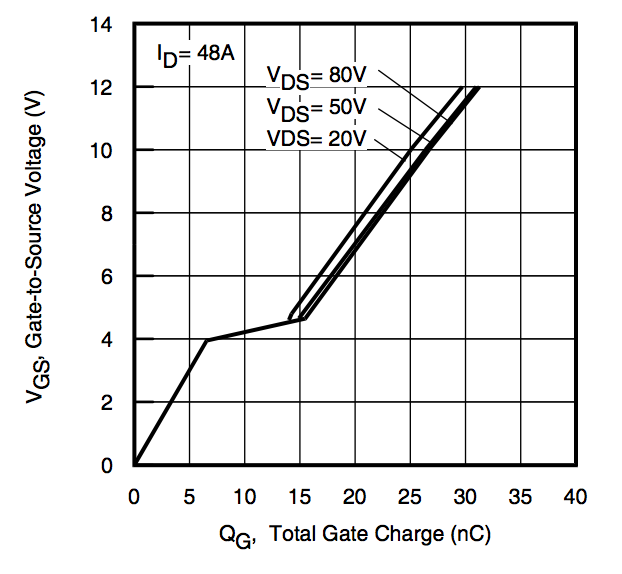
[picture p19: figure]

Figure 7 – MOSFET Gate-to-Source Voltage vs. Gate Charge; Plateau due to the Miller Effect.

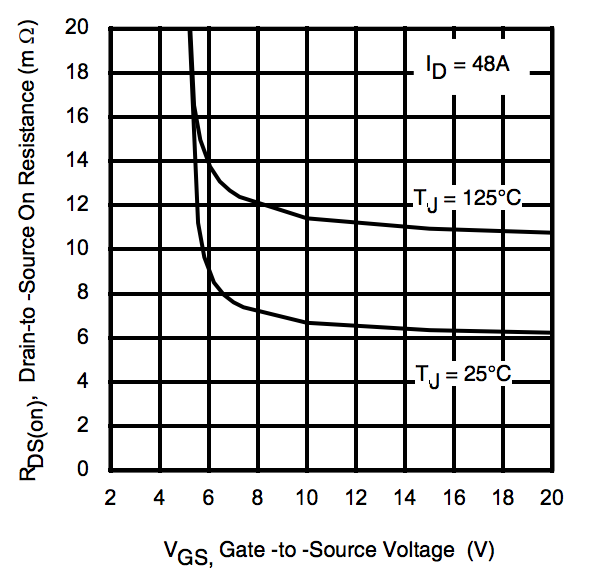
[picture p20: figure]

Figure 8 – MOSFET On-State Resistance vs. Gate-To-Source Voltage.

Thus with the curves in figures 7 and 8 it is possible to determine the MOSFET’s turn-on and turn-off losses [4]. First is the analysis of the three stages of the MOSFET’s turn-off period.

The first stage consists of the MOSFET’s transition from its high on-state gate-to-source voltage (sustained by the gate driver circuit and the MOSFET’s gate capacitance) to the knee in the curves of figures 7 and 8, which is VGS ≈ 6V. Figure shows that during this transition period RDS(on) remains approximately the same as in the MOSFET’s saturation operation region, therefore the losses here are the same as for the MOSFET’s on-state. This period of the switching is still key; however, as a significant portion of the gate charge is dissipated in this period, leading to the second stage of the turn-off period.

In the second stage of the MOSFET’s

Rectifier Diode and Synchronous Rectification

Two approaches are possible for the rectification stage of the power converter, either a high speed switching diode may be used or a MOSFET in synchronous rectification configuration. Using a diode is most straight forward from a converter controller point of view because no additional hardware or software is necessary to control the switching of the diode. This approach has significantly greater power losses; however, as the 0.5V to 1.5V drop across the rectifying diode leads to significant power dissipation in the diode. On the other hand, a MOSFET operating in its saturation has nearly no voltage drop, and thus limited losses. Unfortunately driving two MOSFETs synchronously without crossover is more difficult. Both approaches are explored.

Key characteristics in the selection of a rectifying diode for a buck converter are the ability of the diode to stand up to the voltage and current operating conditions of the power converter and the need to minimize switching losses (by utilizing a diode with a low forward voltage drop, a fast reverse recovery time, and low junction capacitance). Minimizing switching losses is important both for increasing the efficiency of the power converter and in context of selecting a diode which is capable of withstanding the power losses it creates during normal operation. These specifications are summarized in table 5 below.

Parameter | Design Specifications | Part Specifications
Maximum Reverse Voltage | 48V | 60V
Average Rectified Current | 40V | 50V
Maximum Forward Voltage Drop | 2.4V | 1.5V
Maximum Reverse Recovery Time | 100ns | 20ns
Maximum Per-Unit Cost | $10

Table 5 – Rectifying Diode Base Specifications.

The diode component specifications are derived from the characteristics of the power converter. The design specifications are directly related to the converter’s design parameters, while the part specifications included a built in tolerance/factor of safety of approximately 25%. The buck converter’s maximum input voltage dictates the maximum reverse voltage specification. The average rectified current is related to the converter’s maximum output current. The maximum forward voltage drop is derived from the low drop-out voltage of the power converter, which occurs with a 36V input and a 33.6V output. Finally the reverse recovery time is derived from the switching frequency and possible duty cycle values. The 100ns value is derived from the period of a 5% duty cycle at 500kHz. The ability to operate down to a 1% duty cycle would require a maximum reverse recovery time of at most 20ns.

Based on these specifications, the diodes listed in table 6 are potential components for this application. LTSpice simulations were performed on each component to determine each component’s actual suitability for this application.

Part | Price | Maximum Reverse Voltage | Average Rectified Current | Forward Voltage Drop | Reverse Recovery Time | Package
VS-60APU02-N3 | $6.71 | 200V | 60A | 1.08V @ 60A | 28ns | TO-247AC
APT60S20BG | $5.63 | 200V | 75A | 900mV @ 60A | 55ns | TO-247-2

SPICE Model Simulations

As there is a complex interdependence between switching losses, MOSFET heating, MOSFET gate charge, and MOSFET driver current, a SPICE model of the charger circuitry was created to simulate its electrical and thermal characteristics. The model simulations were run using the LTSpice software [9]. The simulation consisted of a buck-converter with models of real-world components, including the LTC4440 MOSFET driver IC. Additionally, MOSFET thermal-analysis was conducted under various circuit loading conditions using MOSFET thermal models provided by the manufacturers. The basic circuit network used for the electrical simulation is show in figure 5, while a basic thermal model is shown in figure 6. It is important to note that the components (such as the MOSFET thermal impedance) in some of these networks are actually macromodels of more complex networks not presented immediately in those figures.

Figure 5 – Buck Converter SPICE network in LTSpice.

Figure 6 – MOSFET Thermal model SPICE network in LTSpice.

The initial model developed was a simple model for conducting baseline tests of various MOSFETs and for verifying model accuracy compared to expected results. Components of the electrical model include the non-ideal inductor L1, ideal filter capacitors with a non-zero ESR, ideal voltage sources for circuit power supply, non-ideal diode models, complex MOSFET models, and a macromodel of the driver IC provided by the manufacturer [10].

The thermal model varied depending on the data provided by the manufacturer. For the International Rectifier MOSFETs, a Foster RC thermal model was used for transient analysis, as the necessary parameters for this model were provided by the manufacturer [6][7][8]. This macromodel was represented by the two-terminal network element R3 (see figure 6). An arbitrary current source (B1) based on the power loss in the MOSFET was used to simulate a heat source, and a DC voltage source (V4) was used to model ambient temperature [11].

A vary of design parameters were tested using SPICE simulations, including inductance values, various MOSFETs, filter capacitance, and inductor saturation characteristics. The follow spice tests were conducted to characterize the circuit:

Test 1: Basic Model Performance

The first tests conducted were simple operation of the converter with a resistive load to verify that the simulation’s nets and models were configured properly. A 48V source was used as the input voltage, with a 500kHz driver signal at 50% duty cycle, in order to provide an expected 24V output to a 1.0-Ohm load. The results of the simulation are presented in figure 7 below.

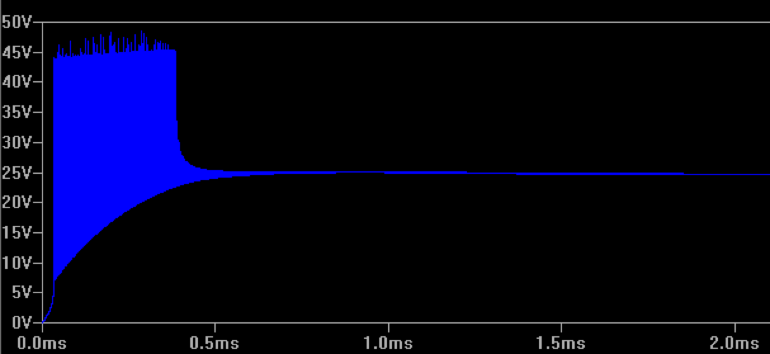
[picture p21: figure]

Figure 7 – Buck-Converter Output Voltage on Startup (Transient Analysis).

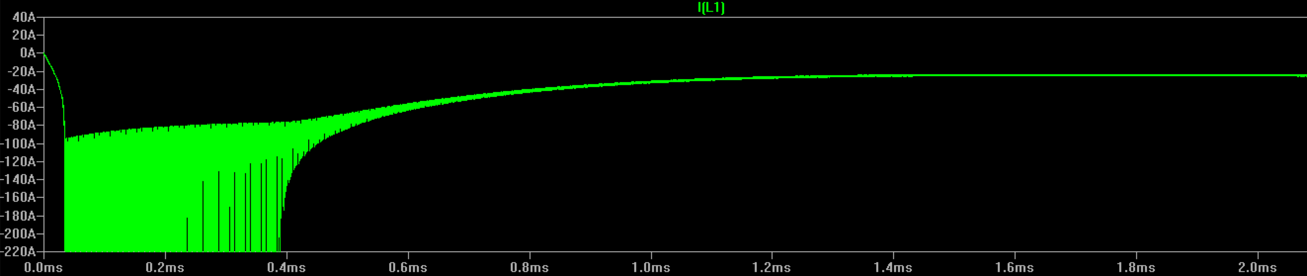
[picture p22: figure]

Figure 8 – Buck-Converter Inductor Current on Startup (Transient Analysis).

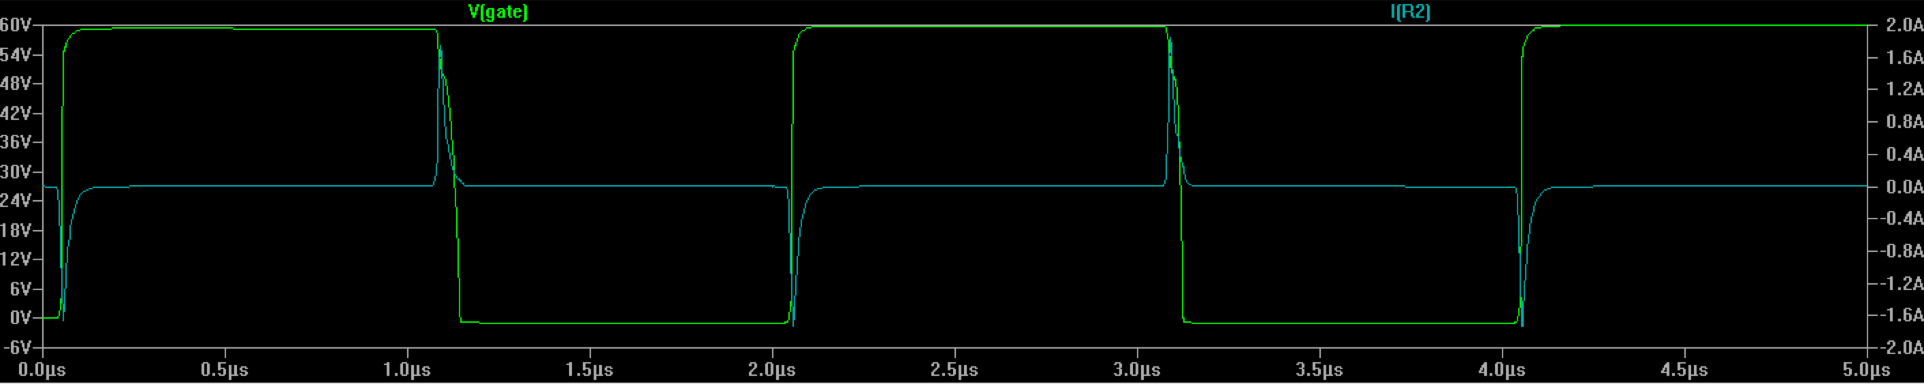
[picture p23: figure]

Figure 9 – Buck-Converter MOSFET Driver Current (Cyan Trace) and MOSFET Gate Voltage (Green Trace).

Figure 10 – MOSFET Junction Temperature in Degrees Celsius.

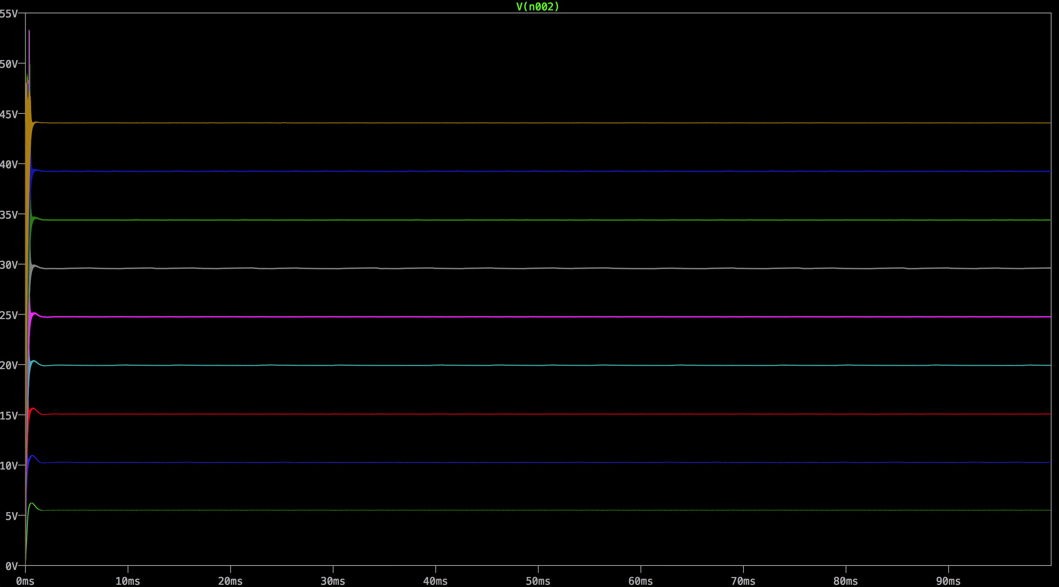
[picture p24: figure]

Figure 11 – Output Voltage for Various Driver Duty Cycles.

Test 2: MOSFET Thermal Analysis in Various Load Conditions

A basic thermal model for the

Test 3: Basic MOSFET Performance Characterizations

Test 4: Load Transient Simulations

References

1. West Coast Inductors 306 Series Datasheet. http://wcmagnetics.wpengine.com/wp-content/uploads/2015/02/wcm306.pdf
2. Coilcraft AGP4233 Series Power Inductor Datasheet. http://coilcraft.com/pdfs/agp4233.pdf
3. Coilcraft AGP4233-223ME Temperature Derating Curve. http://coilcraft.com/misc/agp4233de.html
4. “Estimating MOSFET Switching Losses Means Higher Performance Buck Converters.” Peter Markowski. EE Times. July 11, 2002. http://www.eetimes.com/document.asp?doc_id=1225701
5. Texas Instruments CSD18532KCS Datasheet. http://www.ti.com/lit/ds/symlink/csd18532kcs.pdf
6. International Rectifier IRFH7191 Datasheet. http://www.irf.com/product-info/datasheets/data/irfh7184pbf.pdf
7. International Rectifier IRFH7188 Datasheet. http://www.irf.com/product-info/datasheets/data/irfh7188pbf.pdf
8. International Rectifier IRFH7195 Datasheet. http://www.irf.com/product-info/datasheets/data/irfh7195pbf.pdf
9. Linear Technology’s LTSpice Simulation Software. http://www.linear.com/solutions/ltspice
10. Linear Technology’s LTC4440 High-Side MOSFET driver. www.linear.com/product/LTC4440
11. NXP Semiconductors Application Note 11261: Using RC Thermal Models. http://www.nxp.com/documents/application_note/AN11261.pdf
12. “Power MOSFET Basics.” Vrej Barkhordarian. International Rectifier. http://www.irf.com/technical-info/appnotes/mosfet.pdf
13. LTC6802-2 Multicell Addressable Battery Stack Monitor datasheet. http://cds.linear.com/docs/en/datasheet/68022fa.pdf
14. Texas Instruments MSP432P401R Microcontroller. http://www.ti.com/product/MSP432P401R
15. Texas Instruments MSP432P401R Launchpad Development Board. http://www.ti.com/tool/MSP-EXP432P401R
16. International Rectifier IRLS3034 Power MOSFET datasheet. http://www.irf.com/product-info/datasheets/data/irls3034-7ppbf.pdf
17. Horowitz, Paul, and Windfield Hill. The Art of Electronics. 3rd ed. New York: Cambridge UP, 2015. Print.
18. Linear Technology’s LT1910 Protected High Side MOSFET Driver. http://www.linear.com/product/LT1910
19. Woodbank Communications Ltd. Lithium Battery Failures. http://www.mpoweruk.com/lithium_failures.htm
20. Hyoungkwon, Kim. Product Specification: Rechargeable Lithium Ion Battery Model: 18650HE4 2500mAh. LG Chem. https://cdn.shopify.com/s/files/1/0674/3651/files/LG18650_HE4.PDF?828
21. Andrea, Davide. Battery Management Systems for Large Lithium-Ion Packs. Artech House, 2010. Print.
22. Alegro MicroSystems ACS770 Current Sensor Datasheet. http://www.allegromicro.com/~/media/Files/Datasheets/ACS770-Datasheet.pdf
23. Texas Instruments TLC6C5912-Q1 Power Logic 12-Channel Shift Register LED Driver. http://www.ti.com/lit/ds/symlink/tlc6c5912-q1.pdf
24. Kingbright DC7G3HWA 10 Segment Bar Graph Array. http://www.kingbrightusa.com/images/catalog/SPEC/DC7G3HWA.pdf
25. Hart, Daniel W. Power Electronics. New York: McGraw-Hill, 2011. Print.
26. GNU Octave. https://www.gnu.org/software/octave/

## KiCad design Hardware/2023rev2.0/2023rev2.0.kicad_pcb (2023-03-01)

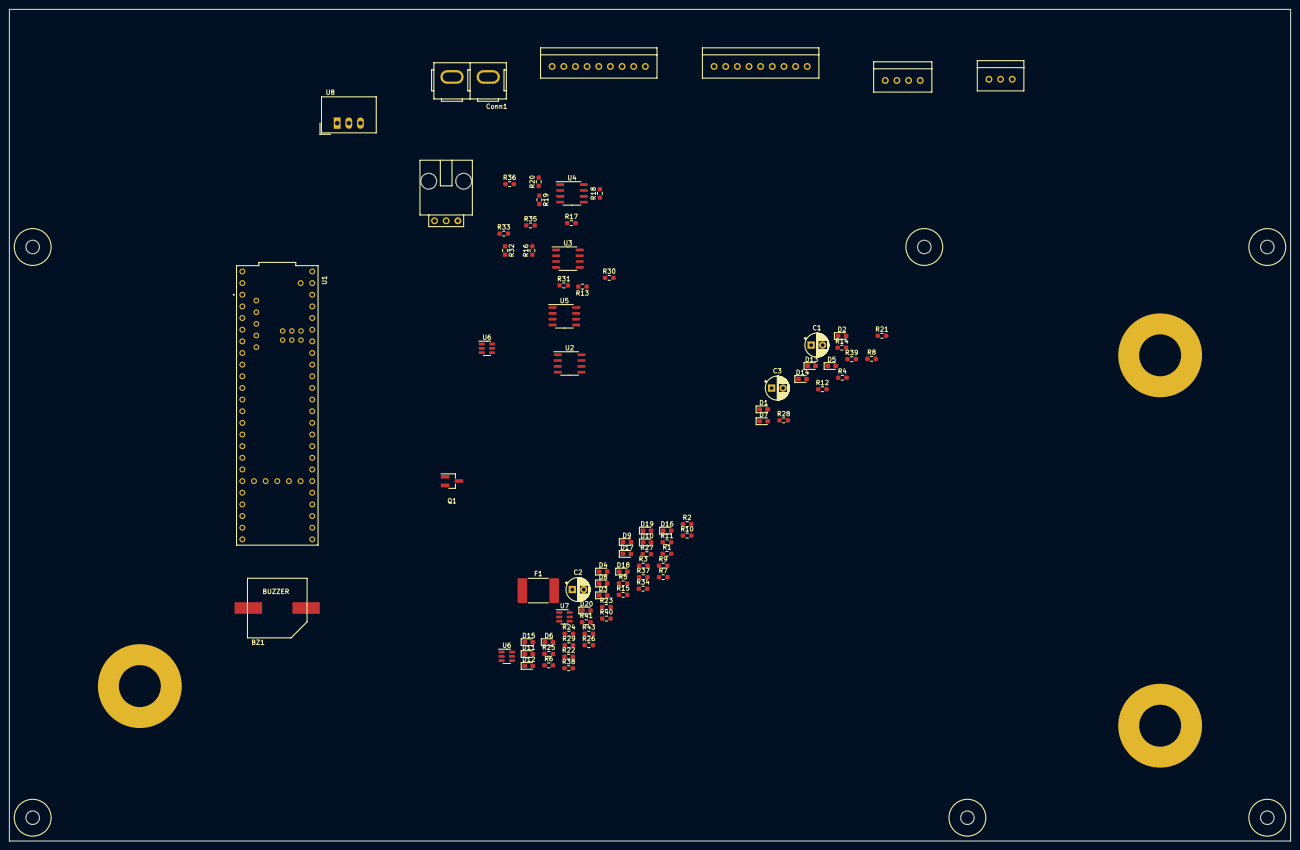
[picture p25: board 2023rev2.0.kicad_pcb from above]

Board: 2 copper layers, 279.4 x 181.4 mm, 92 parts (0 on the bottom side), 57 nets, no tracks yet.

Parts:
BZ1: Buzzer; BUZZER_SMI_1324_TW_5V_2_R
C1: 22uF; CP_Radial_D5.0mm_P2.50mm
C2: 1uF; CP_Radial_D5.0mm_P2.50mm
C3: 10uF; CP_Radial_D5.0mm_P2.50mm
Conn1: AndersonPP; Square_Anderson_2_V_Side_By_Side_PV
D1: ERR; LED_0603_1608Metric_Pad1.05x0.95mm_HandSolder
D2: PACK_OUT; LED_0603_1608Metric_Pad1.05x0.95mm_HandSolder
D3: 5V; LED_0603_1608Metric_Pad1.05x0.95mm_HandSolder
D4: 3V3; LED_0603_1608Metric_Pad1.05x0.95mm_HandSolder
D5, D6, D7, D8, D9, D10, D11, D12: D_Schottky; D_0603_1608Metric_Pad1.05x0.95mm_HandSolder
D13, D14, D15, D16, D17, D18, D19, D20: D_Zener; D_0603_1608Metric_Pad1.05x0.95mm_HandSolder
F1: Polyfuse; Fuse_2920_7451Metric_Pad2.10x5.45mm_HandSolder
H1, H2, H3, H4, H5, H6: MountingHole; 4_40_Hole
J1: Conn_01x03; MOLEX_SL_03_Vertical
J2, J3: Conn_01x09; MOLEX_SL_09_Vertical
J4: Conn_01x04; MOLEX_SL_04_Vertical
Q1: Q_NMOS_DGS; SOT-23_Handsoldering
R1: 100K; R_0603_1608Metric_Pad0.98x0.95mm_HandSolder
R2: 4.7k; R_0603_1608Metric_Pad0.98x0.95mm_HandSolder
R3: 820; R_0603_1608Metric_Pad0.98x0.95mm_HandSolder
R4, R43: 10k; R_0603_1608Metric_Pad0.98x0.95mm_HandSolder
R5, R8: 100; R_0603_1608Metric_Pad0.98x0.95mm_HandSolder
R6: 3k; R_0603_1608Metric_Pad0.98x0.95mm_HandSolder
R7: 300; R_0603_1608Metric_Pad0.98x0.95mm_HandSolder
R9, R10, R11, R12, R13, R14, R15, R16, R17, R18, R19, R20, R21, R22, R23, R24: 31.5k; R_0603_1608Metric_Pad0.98x0.95mm_HandSolder
R25, R26, R27, R28, R29, R30, R31, R32, R33, R34, R35, R36, R37, R38, R39, R40: 40k; R_0603_1608Metric_Pad0.98x0.95mm_HandSolder
R41: 4k; R_0603_1608Metric_Pad0.98x0.95mm_HandSolder
SW1: SW_SPDT; MOLEX_SL_03_Horizontal
U1: Teensy4.1_DEV-16771; Teensy_4_1
U2, U3, U4, U5: Opamp_Dual; SO-8_3.9x4.9mm_P1.27mm
U6, U6#2, U7: INA195; SOT-23-6
U8: TSR_1-2450; Converter_DCDC_TRACO_TSR-1_THT
V1: BATT_GND_VIA; BATT_PWR_VIA
V2: BATT_PWR_VIA
V3: BMS_OUT_VIA; BATT_PWR_VIA

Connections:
+3.3V: C2.1, C3.1, J1.1, R8.2, U6.5 (V+), U6#2.5 (V+), U7.5 (V+)
+5V: BZ1.1 (-), R7.2, U2.8 (V+), U3.8 (V+), U4.8 (V+), U5.8 (V+), U8.3 (Vout)
GATE: J4.2, U1.41 (A17)
GND: C1.2, C2.2, C3.2, D1.1 (K), D2.1 (K), D3.1 (K), D4.1 (K), D12.2 (A), D13.2 (A), D14.2 (A), D15.2 (A), D16.2 (A), D17.2 (A), D18.2 (A), D19.2 (A), D20.2 (A), J1.3, J2.1, J3.1, J4.4, Q1.3 (S), R2.1, R3.2, R9.2, R11.2, R13.2, R15.2, R17.2, R19.2, R21.2, R23.2, R40.1, R43.1, U2.4 (V-), U3.4 (V-), U4.4 (V-), U5.4 (V-), U6.2 (GND), U6#2.2 (GND), U7.2 (GND), U8.2 (GND)
unnamed: BZ1.2 (+), Q1.1 (D)
unnamed: C1.1, SW1.2 (B), U8.1 (Vin)
unnamed: Conn1.1 (GND), V1.1
unnamed: D5.1 (K), D13.1 (K), J3.9, R25.1, V2.1
unnamed: D1.2 (A), R5.1
unnamed: D2.2 (A), R6.1
unnamed: D3.2 (A), R7.1
unnamed: D4.2 (A), R8.1
unnamed: D9.2 (A), D10.1 (K), D18.1 (K), J3.4, R34.1, R35.1
unnamed: D10.2 (A), D11.1 (K), D19.1 (K), J3.3, R36.1, R37.1
unnamed: D11.2 (A), D12.1 (K), D20.1 (K), J3.2, R38.1, R39.1
unnamed: D5.2 (A), D6.1 (K), D14.1 (K), J3.8, R26.1, R27.1
unnamed: D6.2 (A), D7.1 (K), D15.1 (K), J3.7, R28.1, R29.1
unnamed: D7.2 (A), D8.1 (K), D16.1 (K), J3.6, R30.1, R31.1
unnamed: D8.2 (A), D9.1 (K), D17.1 (K), J3.5, R32.1, R33.1
unnamed: F1.2, SW1.1 (A)
unnamed: J1.2, U1.21 (A7)
unnamed: J4.3, R41.1
unnamed: Q1.2 (G), R2.2, U1.20 (A6)
unnamed: R1.1, R4.1, U1.19 (A5)
unnamed: R3.1, R4.2
unnamed: R5.2, U1.22 (A8)
unnamed: R10.1, R26.2, U2.6 (-)
unnamed: R10.2, U1.40 (A16), U2.7
unnamed: R11.1, R27.2, U2.3 (+)
unnamed: R12.1, R28.2, U2.2 (-)
unnamed: R12.2, U1.39 (A15), U2.1
unnamed: R13.1, R29.2, U3.5 (+)
unnamed: R14.1, R30.2, U3.6 (-)
unnamed: R14.2, U1.38 (A14), U3.7
unnamed: R15.1, R31.2, U3.3 (+)
unnamed: R16.1, R32.2, U3.2 (-)
unnamed: R16.2, U1.27 (A13), U3.1
unnamed: R17.1, R33.2, U4.5 (+)
unnamed: R18.1, R34.2, U4.6 (-)
unnamed: R18.2, U1.26 (A12), U4.7
unnamed: R19.1, R35.2, U4.3 (+)
unnamed: R20.1, R36.2, U4.2 (-)
unnamed: R20.2, U1.25 (A11), U4.1
unnamed: R21.1, R37.2, U5.5 (+)
unnamed: R22.1, R38.2, U5.6 (-)
unnamed: R22.2, U1.24 (A10), U5.7
unnamed: R23.1, R39.2, U5.3 (+)
unnamed: R24.1, R40.2, U5.2 (-)
unnamed: R24.2, U1.23 (A9), U5.1
unnamed: R9.1, R25.2, U2.5 (+)
unnamed: U6#2.3 (+), U7.4 (-)
unnamed: U6#2.4 (-), U7.3 (+)
unnamed: U1.3.3V_1 (3.3V), U1.3.3V_2 (3.3V), U1.3.3V_3 (3.3V)
unnamed: U1.12 (MISO), U6.1, U6#2.1
unnamed: U1.GND1 (GND), U1.GND2 (GND), U1.GND3 (GND), U1.GND4 (GND), U1.GND5 (GND)
unnamed: U1.USB_GND1 (USB_GND), U1.USB_GND2 (USB_GND)
PACK_OUT: R1.2, R6.2, R41.2, R43.2, V3.1

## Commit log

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2015-06-29 Added E-Stop connectors, powersupplies (12V, 5V), additional cell tap line connector for off-board measurements
    [PP-Rev1.brd, PP-Rev1.sch]
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2015-06-29 Fixed pull-up resistor on LED driver. Added buzzer alarms
    [PP-Rev1.brd, PP-Rev1.sch]
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2015-09-30 Small schmatic fixes
    [PP-Rev1.sch]
2015-09-30 Added launchpad microcontroller library file and into schematic/board. Updated LCD connections to better utilize microcontroller port architecture
    [PP-Rev1.brd, PP-Rev1.sch]
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2015-10-11 additional work on board layout. Changed charger input terminals from bolt holes to large screw terminal
    [PP-Rev2.brd, PP-Rev2.sch]
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2015-10-14 Lots of power supply routing. Merged two independent 5V supplies into one supply
    [PP-Rev2.brd, PP-Rev2.sch]
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2015-10-14 Fixed lots of DRC errors. Just a few overlaps left.
    [PP-Rev2.brd]
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2015-10-16 Fixed issue with poor pack ground return net placement
    [PP-Rev2.brd]
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2015-10-18 Fixed last DRC errors
    [PP-Rev2.brd]
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2015-10-20 Create gerbers for charger prototype. Update Gerber README file to include additional information
    [Battery-Charger-Prototype.GBL, Battery-Charger-Prototype.GBO, Battery-Charger-Prototype.GBS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]
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2015-10-27 Fixed middle pad on MOSFET part
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2015-10-29 Complete SPICE sim for 90% duty cycle case. Updated Eagle files with proper MOSFET
    [PP-Rev2.brd, PP-Rev2.sch]
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2015-11-13 Reconfigure board and schematic to include second MOSFET to make synchronous switching possible on the buck converter
    [PP-Rev2.brd, PP-Rev2.sch]
2015-11-17 Update board power supply to use proper input/output filtering caps, properly sized PTC fuse on input from battery pack
    [PP-Rev2.brd, PP-Rev2.sch]
2015-11-17 Generate gerber files for power supply and MOSFET footprint corrections
    [PP-Rev2.brd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]
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2015-11-18 Made the LED bargraph PCB smaller, added hole for on/off switch mounting
    [LED-Gauge-Panel.brd, LED-Gauge-Panel.dxf]
2015-11-18 Create library part for LED display button, update PCB with LED button part
    [LED-Gauge-Panel.brd, LED-Gauge-Panel.dxf, LED-Gauge-Panel.sch]
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2016-09-30 First complete BMS schematic
    This is the frist complete version of the 2017 BMS schematic. The PCB
    has been started, but is nowhere near complete.
    Just before CDR
    [BMS.brd, BMS.sch]
2016-10-07 PCB progress
    First attempt at PCB design for BMS is mostly done
    [BMS-before routing.brd, BMS-before routing.sch]
2016-10-13 PCB attempt #4
    PCB redesigned for actual mounting and connection concerns, now approx
    5" on each side. Now with labels! Ready for review.
    [BMS-before routing.brd, BMS-before routing.sch, BMS.brd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]
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2016-10-16 Changed after board review
    Made all changes suggested in pcb review, including several part
    additions and complete rerouting.
    [BMS.brd, BMS.sch]
2016-10-22 Changes for mountability
    Changed GND terminal to Anderson connector, moved to opposite corner.
    Changed package for current sensor, added connector for indicator
    connection, swapped all data connectors for molex SLs
    [BMS.brd, BMS.sch]
2016-10-23 DRC error fixes
    Fixed several traces changed due to moving GND, and flipped signiture to
    top.
    [BMS.brd, BMS.sch]
2016-10-23 Fixed label sizes
    [BMS.brd]
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2016-10-24 Swapped RS485 for RS232
    Changed MAX3077 (rs485) for MAX232. Indicator and Powerboard
    communication now separate. Also rerouted LED driver and fan traces.
    [BMS.brd, BMS.sch]
2016-10-24 Tidying up and part swap
    Rounded dimensions 5"x5.2", rearranged labels, updated connectors to
    sync with MRDT-Connectors, rearranged vias.
    Changed out MAX232 (5V operation) for MAX3232 (3V to 5V)
    [BMS.brd, BMS.sch]
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2016-11-05 Component changes and decreasing the size of the board
    Changed from using the arduino micro to the now using the ATMEGA328P
    microchip. Also changed the the the Max232D so that we can run of 5
    volts and we no longer have 3.3V on the board. The voltage display and
    the push button have now been moved to the back so that we can make the
    board smaller. The transisors were replaced with Mosfets and a crystal
    and programming pins were added. The board is now also receiving its
    power, and data from bsm via serial line.
    [LED-Gauge-Panel.brd, LED-Gauge-Panel.dxf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]
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2016-11-18 Review 2 changes
    Changed from n channel mosfets to p channel. Removed the resistors on
    the control lines to the mosfets.
    moved the resistors in series with the programming pins. And put
    capacitors in the VCC lines.
    [Voltage meter_Rev1.brd, Voltage meter_Rev1.sch]
2016-11-19 Modifications from second review
    The atmega chip was changed to be surface mount. Wires were rerouted and
    DRC was run. Capacitors added as well.
    [Voltage meter_Rev1.brd, Voltage meter_Rev1.sch]
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2016-12-27 Reroute and label
    Minor changes made to the positioning of the capacitors. Some traces
    were changed due to the capacitor changes and some changes were made to
    keep the trace from jumping between levels. Labels were positioned on
    the board and MRDT symbol was placed on the board as well as a brief
    board discription.
    [Voltage meter_Rev1.brd, Voltage meter_Rev1.sch]
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2017-01-12 Intermediate rearrangement
    Minor circuit corrections to schematic and beginning of rearrangement of
    PCB
    [BMS.brd, BMS.sch]
2017-01-12 Final edits to Indicator Board
    Small corrections- Moved some vias, added mounting holes, adjusted
    sides.
    [Voltage meter_Rev1.brd, Voltage meter_Rev1.sch]
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2017-01-31 Some Schematic edits, major PCB rearrangment
    fixed reset coil circuit, removed on board fuel gauge (connectors for off-board still there), changed SCLK pin.
    PCB is mostly rearranged but not routed. still preliminary.
    [BMS.brd, BMS.sch]
2017-02-03 PCB rearrangement for review
    Rearranged entire board for ease of connections, mostly in main power but also everything else. Provisionary design pending mechanical redesign of battery pack and box.
    [BMS.brd, BMS.sch]
2017-03-12 changed LTC pins, update for reference
    Switched around ltc and rs232 pins so they catually work, corrected ltc hookup.
    PCB is not complete, due to changes
    [BMS.brd, BMS.sch]
2017-03-20 Ready for review for Final Hardware
    finished PCB routing, moved stuff around for wiring purposes, moved signiture and text to back, moved pack sense voltage divider to other side of logic switch to reduce trickle current, etc.
    [BMS.brd, BMS.sch]
2017-03-22 Routing fixes after review
    moved 5V line to not be on edge, flipped Pack Sense connector to back for ease of connection, fixed gnd vias
    [BMS.brd]
2017-03-22 Last edits before order
    Fixed some labels and traces, signiture, text
    [BMS.brd]
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2017-03-22 Fixed overlapping traces, messed up saves
    i screwed up a couple times, commited before i was actually ready. this version is ready for ordering. scout's honor.
    [BMS.brd]
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2018-03-14 Rev2; added ADC buffer opamp, new estop connector, fixed mux508 VDD/VSS, and added bypass caps
    [BMS.brd, BMS.sch]
2018-03-15 Cleaned up estop lamp trace, added estop silkscreen and additional via stitching around AD8655 traces
    [BMS.brd]
2018-03-15 Fixed naming on via stitching
    [BMS.GBL, BMS.GBO, BMS.GBP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]
2018-03-15 Fixed naming on via stitching, added rev2 title on silkscreen
    [BMS.brd]
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2018-04-12 Fixed missing passive values
    [BMS_Hardware.sch]
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2018-04-16 Added Buzzer Alarm
    [BMS_Hardware.sch]
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2018-10-13 new micro controller in schematic
    Implemeneted the new micro_controler into the schematic and added resistor to temp sensor
    [BMS_Hardware-2018-10-13-14-11-54.sch, BMS_Hardware.sch]
2018-10-13 small schematic layout change
    Changed the size of the communications and indicators box
    [BMS_Hardware.sch]
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2018-10-13 fixed a few global lables for new microcontroller
    [BMS_Hardware.sch]
2018-10-13 Schematic layout changes
    rearranged the layout of the schematic to make room for the voltage dividers for the cell filter section
    [BMS_Hardware.sch]
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2018-10-21 Added Tiva_Top_SMD; Loaded board layout
    Libraries are not mapped correctly, the layout cannot pull correct packages
    [BMS_Hardware.kicad_pcb, BMS_Hardware.sch]
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2018-10-26 schematic fix
    [BMS_Hardware.sch]
2018-10-27 beginning board fix cause i be dumb
    [BMS_Hardware.kicad_pcb]
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2018-12-08 Schematic rework (renamed flags and reordering diffopamps)
    [BMS_Hardware.kicad_pcb, BMS_Hardware.sch]
2018-12-08 finished diffopamp rework
    [BMS_Hardware.sch]
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2019-03-02 Revert "Rev2 changes minus silkscreen"
    This reverts commit 6f5c0bf1a9069706d610c9b31c67a74d4d99d24d.
    [BMS_Hardware-BSilkS.dxf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]
2019-03-02 file problems fixed
    [BMS_Hardware.kicad_pcb, BMS_Hardware.sch]
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2019-10-04 schematic almost done
    Still planning how to change diffops amps and currently putting in microcontroller
    [2020_BMSBOARD.sch]
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2019-10-06 schematic almost done
    Just need microcontroller pinouts and we changed the diffop amps to op amps with resisters
    [2020_BMSBOARD.sch]
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2019-10-06 fixed issues
    [2020_BMSBOARD.sch]
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2019-10-25 everything is on the new board that is supposed to be there
    [2020_BMSBOARD.kicad_pcb]
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2019-11-04 fixed opamps
    the opamps were backwards and wrong so fixed them
    [2020_BMSBOARD.sch]
2019-11-04 Dan please look at this
    Tiva pins have been moved (like the inputs for stuff)
    [2020_BMSBOARD.kicad_pcb, 2020_BMSBOARD.sch]
2019-11-04 hey dan here I am again
    this time we fixed some more stuff woaaah
    [2020_BMSBOARD.kicad_pcb]
2019-11-05 fixed the layout
    there were duplicate resistors it was weird
    [2020_BMSBOARD.kicad_pcb]
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2019-11-09 1-smaller board, 2-tiva
    changed to breakout board for Tiva, and now the board is 6.7 inches ish rather than 8.2
    [2020_BMSBOARD.kicad_pcb]
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2019-11-11 fixed a trace
    [2020_BMSBOARD.kicad_pcb, 2020_BMSBOARD.sch]
2019-11-12 schematic: op amps, layout: traces
    the op amps were wired incorrectly. The netlist was updated in the layout, and in the layout more traces were made
    [2020_BMSBOARD.kicad_pcb, 2020_BMSBOARD.sch]
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2019-11-14 Revert "Op AMP Cells created"
    This reverts commit 6ad7e5cb3c10f5f3e9d186cb0fb9112252808f15.
    [2020_BMSBOARD.kicad_pcb]
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2019-11-15 stitching fixed
    [2020_BMSBOARD.kicad_pcb]
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2019-11-21 more progress....
    the fan controls have been wired to the tiva breakout, some wires have been changed to back to provide a more clear path for the GND pin
    [2020_BMSBOARD.kicad_pcb, 2020_BMSBOARD.sch]
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2019-11-21 documentation files fixed
    [BMS_Hardware-BSilkS.dxf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]
2019-11-22 changed schematic to almost all be on 50 grid
    also changed the tiva footprint so it isn't broken, changed some more schematic things
    [2020_BMSBOARD.kicad_pcb, 2020_BMSBOARD.sch]
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2020-02-14 Tiva Board Footprint updated and traces fixed
    [2020_BMSBOARD.kicad_pcb, 2020_BMSBOARD.sch]
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2020-10-13 buzzer started, 5v buck needs R values
    [5V_BUCK.sch, BMS_2021_Rev1.sch, CURRENT_SENSE.sch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]
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2020-10-18 notes from PDR made. to be fixed
    [3V3_BUCK.sch, 5V_BUCK.sch, BMS_2021_Rev1.sch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]
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2020-11-16 buzzer done, 5v and 3v3 routed to various ICs
    [3V3_BUCK.sch, 5V_BUCK.sch, BMS_2021_Rev1.kicad_pcb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]
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2020-11-17 got new board dimentions, moved right side vias into position, TODO: fix stuff around it
    [BMS_2021_Rev1.kicad_pcb]
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2020-11-21 bucks moved, need to replace w okis
    [BMS_2021_Rev1.kicad_pcb]
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2020-11-22 replaced bucks w okis in schematic, generated netlist
    [3V3_BUCK.sch, 5V_BUCK.sch]
2020-11-22 connceted hall sensor to PV and V_in planes, added Conn(s) F.silk
    Accidentially deleted the mounting holes, will replace
    [BMS_2021_Rev1.kicad_pcb, BMS_2021_Rev1.sch]
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2020-11-22 did some stitching, done for the day.
    ToDo: Fix cellFiltering by moving the schot. diodes and filtering caps towards connector and the zener diodes to the tiva
    [BMS_2021_Rev1.kicad_pcb]
2020-11-23 fixed sch symbol libraries (see desc) and generated a new netlist. will begin fixing the cellFilters
    Could not find th esymbol for the cellFilter IC so I had to remap it. The schottky diode symbol gave me some trouble too
    [BMS_2021_Rev1.kicad_pcb, CELL_FILTERS.sch]
2020-11-23 Fixed cellFilter schematic by moving diodes btwn cells, generated new netlist
    [3V3_BUCK.sch, 5V_BUCK.sch, BMS_2021_Rev1.kicad_pcb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]
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2020-11-24 Revert "continued wiring the cellFilters. cells 1-7 are now done (working on improvements)"
    This reverts commit 30bd659c1e722bf1891392f90f37f2d2aea567cf.
    [BMS_2021_Rev1.kicad_pcb]
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2020-11-24 reinforce gnding around charging port
    [BMS_2021_Rev1.kicad_pcb]
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2021-01-16 Revert "moved OKIs closer to each other, added logic_power plane, currently redrawing power traces to make room for PV plane extension"
    This reverts commit 67f00ba41ba6f96b0cb7a188f9ff7f3cd271433a.
    [BMS_2021_Rev1.kicad_pcb]
2021-01-16 rev2 branch created and populated with changes
    these changes were accidently made to the wrong branch
    [3V3_BUCK.sch, 5V_BUCK.sch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]
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2021-02-23 r7 moved to correct orientation
    [BMS_2021_Rev1.kicad_pcb]
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2021-03-12 moving LCD and Temp connectors to allow for better mounting
    may revert back to previous commit, undecided.
    [BMS_2021_Rev1.kicad_pcb]
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2021-03-13 LED and resistors swapped locations.
    Power draw to go through resistor first to prevent destroying LED
    [BMS_2021_Rev1.kicad_pcb, FEEDBACK_LED_BUZZ.sch]
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2021-04-02 replaced cellFilter ICs with last gen chip
    Replaced with the chipset alisa used because they are more reliable and work better based off of bench testing of my chip.
    [CELL_FILTERS.sch]
2021-04-02 CF replacement 75% done, rerouted 5V and 3V3 traces
    [BMS_2021_Rev1.kicad_pcb, CELL_FILTERS.sch]
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2021-10-03 Hierarchy sheets fixed
    Created files in the file folder for the schematics
    [Buzzer Alarm.sch, Cell Filters.sch, Control.sch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]
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2021-10-04 Started Building LED Indicators, Voltage Converter, Buzzer Alarm, E-Stop, Communication and Fan Power / Control
    The electrical data is still needed for example the resistance for all the resistors is needed still.
    [BMS_2022_Rev1.sch, Buzzer Alarm.sch, Cell Filters.sch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]
2021-10-05 Removed Autosaved Rescue Library
    Removed Rescue Library because of Github push issues
    [BMS_2022_Rev1.kicad_pcb, BMS_2022_Rev1.sch]
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2021-10-06 Fixed LED Indicator
    Placed Labels for LED indicator and labeled communication Serial Text
    [BMS_2022_Rev1.sch]
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2021-10-13 Board Review Changes
    Changed pins on the missing points connected to components during board review
    [BMS_2022_Rev1.sch]
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2021-10-17 consistency check
    added missing tag, wires
    [2022Rev1.kicad_pcb, 2022Rev1.sch, BMS_2022_Rev1.sch]
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2021-10-23 Fixed labels
    changed the directions of the labels to properly be organized for ladybug debugger
    [BMS_2022_Rev1.sch]
2021-11-05 reworking 3-way networkswitch
    Remapping 3-way network switch for logic simplification and power flow to mosfet
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2021-11-13 Replaced Differential Op-Amp because of Chip Shortage
    Replace Differential Op-Amp because of chip shortage and replaced the schematic layout of Cell Monitor with the Generic Differential Op-Amp layout with matching resistor and diode values of the Differential Op-Amp ordered
    [BMS_2022_Rev1.sch]
2021-11-13 Deleted BMS Logic Switch and fixed: no connects, flags, and cell voltage monitor connections
    Completed Troubleshooting for Ladybug by simplifying BMS schematic. Deleted BMS Logic Switch since we have 3 way switch. Fixed flags and no connect issues for Ladybug problem analysis
    [BMS_2022_Rev1.sch]
2021-11-13 Replaced SL Molex connectors with Microfit Molex connectors
    Replaced SL Molex connectors with Micro fit Molex connectors because Micro fit is more structurally sound
    [BMS_2022_Rev1.sch]
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2021-11-18 Started Creating the PCB and flipped the Mosfet Gate driver across the y-axis
    Started to create the PCB and realized the issue of the mosfet gate driver not facing the right way, but it has been fixed
    [BMS_2022_Rev1.csv, BMS_2022_Rev1.kicad_pcb, BMS_2022_Rev1.sch]
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2021-11-27 Reworking BMS Traces and overall layout
    Removed BMS Traces and components to re-organize and to properly place the correct traces and power planes on BMS to meet BMS requirements
    [BMS_2022_Rev1.kicad_pcb]
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2021-12-01 BMS Preliminary Design Complete
    BMS Preliminary Design completed for the 2nd part of board review. We will review the board and make changes before the board order date to hopefully prevent from ordering many different boards
    [BMS_2022_Rev1.kicad_pcb, BMS_2022_Rev1.sch]
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2021-12-03 Fixing connector pin labels
    Fixing connector pin label positions and names to help clarify what each pin is
    [BMS_2022_Rev1.kicad_pcb]
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2021-12-10 Finished Fixing Silk Screen Labels and Made Gerber Files
    Finished Fixing Silk Screen Labels and Made Gerber Files which were tested and are good to go for manufacturing
    [BMS_2022_Rev1-B_Cu.gbr, BMS_2022_Rev1-B_Mask.gbr, BMS_2022_Rev1-B_Paste.gbr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]
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2022-02-18 Recommiting from Onedrive issues
    [BMS_2022_Rev1.kicad_pcb, BMS_2022_Rev1.sch]
2022-02-18 Started the rework of BMS with four layers added
    [BMS_2022_Rev1.kicad_pcb]
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2022-02-24 fix the connector
    [BMS_2022_Rev1.kicad_pcb]
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2022-03-15 Fixed differential pairing and replaced the buck
    [BMS_2022_Rev1-B_Cu.gbr, BMS_2022_Rev1-B_Mask.gbr, BMS_2022_Rev1-B_Paste.gbr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]
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2022-03-19 Added drill holes, edge cutts, fixed traces created Gerbs
    [BMS_2022_Rev1-B_Cu.gbr, BMS_2022_Rev1-B_Mask.gbr, BMS_2022_Rev1-B_Paste.gbr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]
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2022-03-20 fix diff pair on ethernet, gerbs
    pins 1&2 on the ethernet connectors are now 0.2 mil difference
    [BMS_2022_Rev1-B_Cu.gbr, BMS_2022_Rev1-B_Mask.gbr, BMS_2022_Rev1-B_Paste.gbr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]
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2022-10-04 fixed filesystem
    [2023rev2.0.kicad_pcb, 2023rev2.0.kicad_sch, 2023rev2.kicad_sch]
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

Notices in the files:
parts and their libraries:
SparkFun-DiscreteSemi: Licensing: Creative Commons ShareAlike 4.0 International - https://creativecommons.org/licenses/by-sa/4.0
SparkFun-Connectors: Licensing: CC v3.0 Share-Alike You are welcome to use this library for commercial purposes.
